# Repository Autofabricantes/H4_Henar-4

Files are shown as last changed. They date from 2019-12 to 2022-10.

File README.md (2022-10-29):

# Henar-4

Hi! Welcome to the **Henar#4 Repository**, please read carefully this welcome page that describes the full content.

This repository is may miss some important points (after many months, I know :'( ) Please if whatever doubt you have is not yet solved contact us somehow (email, Github, etc)

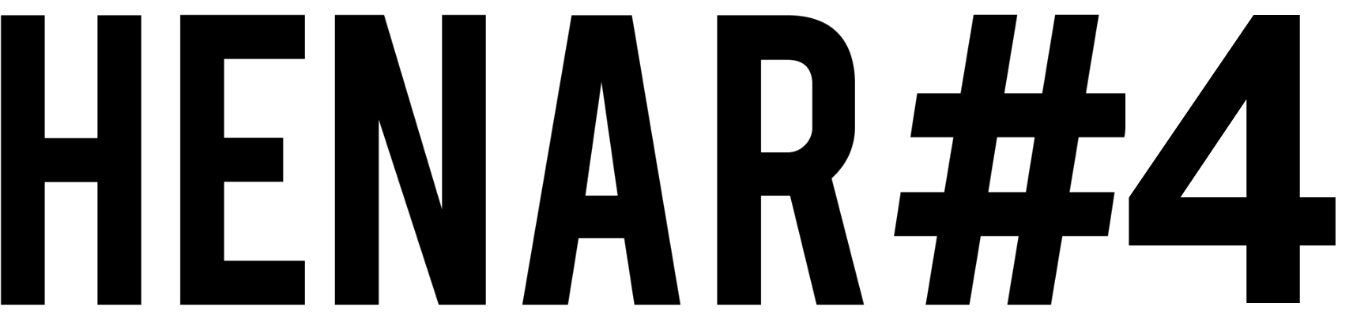
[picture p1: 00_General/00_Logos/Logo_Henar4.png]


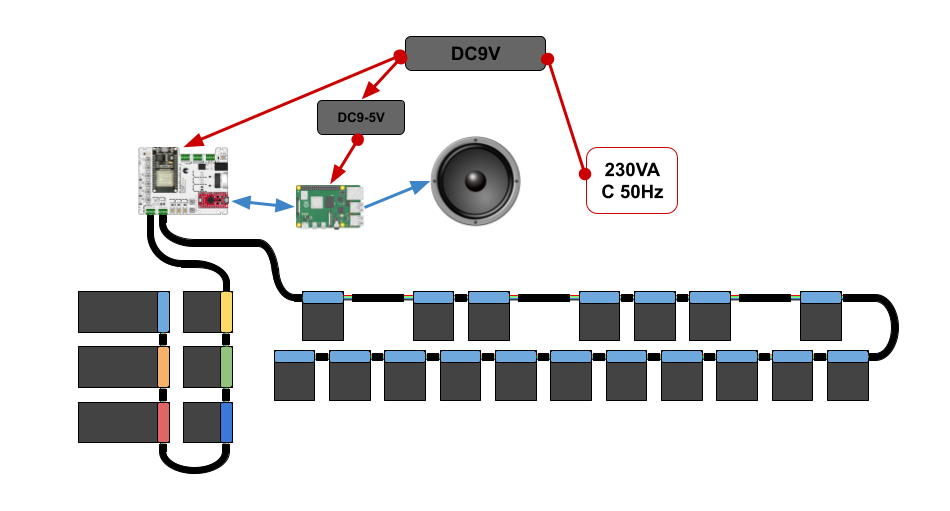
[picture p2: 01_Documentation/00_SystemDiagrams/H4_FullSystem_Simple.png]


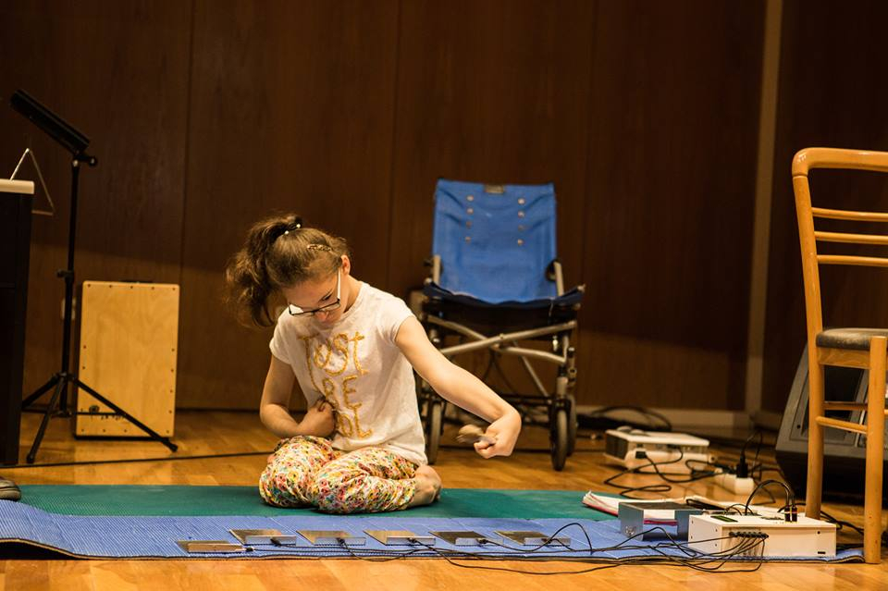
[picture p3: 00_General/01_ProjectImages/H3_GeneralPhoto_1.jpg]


## Project Scope
The **Henar#4** is a Open Source MIDI percussion instrument designed to perform live. Its main characteristics are:

**Open Source:** The Henar#4 has been designed and build with Open Source HW and SW and using accesible manufacturing technologies in order for it to be very affordable and easily moded.
**Build Flexibility:** The Henar#4 has been designed to allow a large number of different configurations (HMI elements in order to cope with the specific neccessities of each user.
**Stand Alone:** The Henar#4 is an instrument designed to be played live, therefore it is a Plug&Play device which does not need of extra elements to be played.
**Pheriperic Flexibility:** Besides being a Plug&Play device, the Henar#4 allows its connection with other sound devices such as speakers and alternative MIDI devices.
 
## History and Collaborators
The Henar#4 is part of a longer project started by the _Celeo Proyectos_ and _Un Instrumento para Henar_ in 2015. Its initial objective is to build a proper adapted instrument for Henar, a woman from Cuenca (Spain) that plays in an orchestra.

Apart from the instrument (which has three previous versions which will be described later) the project aims to build up a platform for the community of developers, users and enthusiasts to work toguether towards new ways to socialize with music and make it accesible for everyone. This is achieved not only though the development of the instrument itself but also through the creation of didactic materials and the organization of events such as DiverS+S 2017 (http://www.diversos.eu/), where various projects were presented and put in common, in order to create links and an active net.

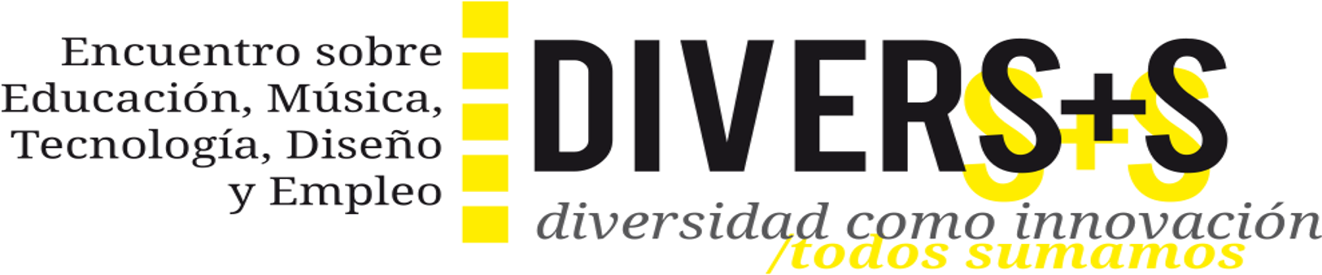
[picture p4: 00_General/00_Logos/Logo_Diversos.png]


The collaborators of this project are:
## Celeo Proyectos

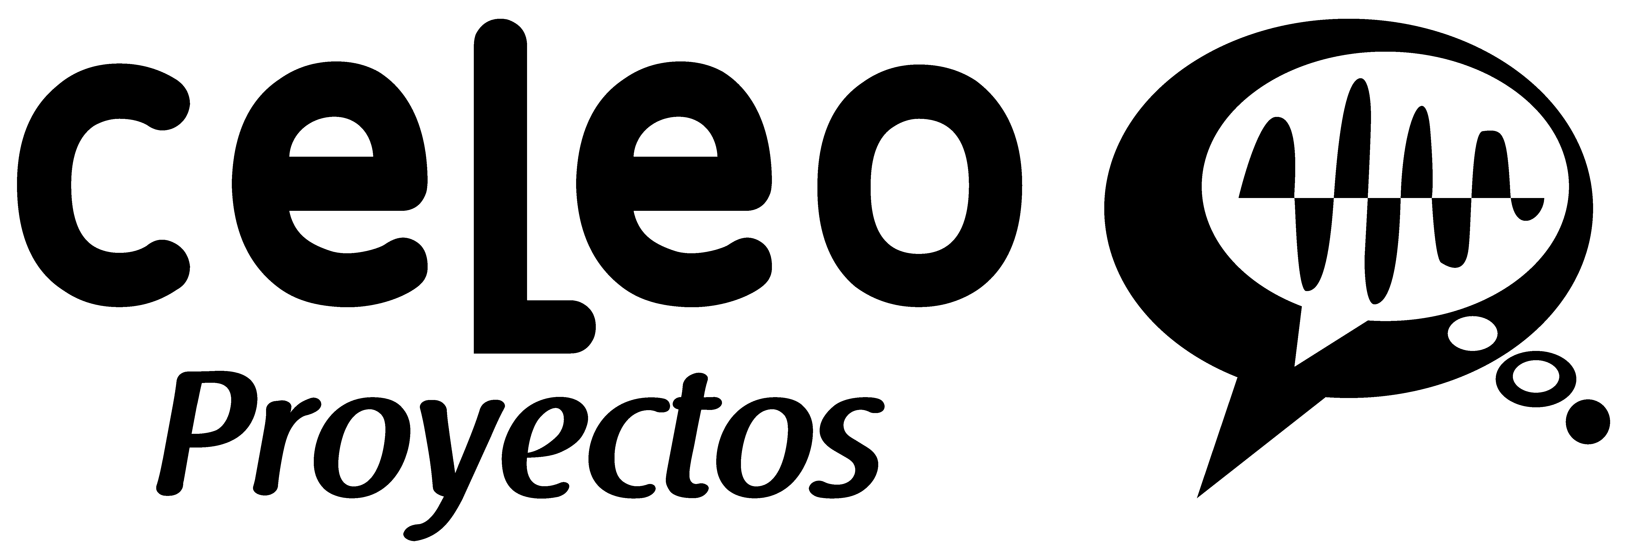
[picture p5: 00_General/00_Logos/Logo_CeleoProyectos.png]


## Un instrumento para Henar



### Website: www.centroceleo.es/henar
### Contact: uninstrumentoparahenar@gmail.com

## Autofabricantes
**_Autofabricantes_** in an association based in _Medialab-Prado_, Madrid. It develops several _Open Source_ technological solutions in the medical and accesibility field. It's main development lines right now are:
* Myoelectric Hand Prothesis for children.
* 3D printed hand prosthesis for children (both experimental like __SuperGizz__ and standard).
* **_Henar#3_** instrument (The one this Wiki covers).

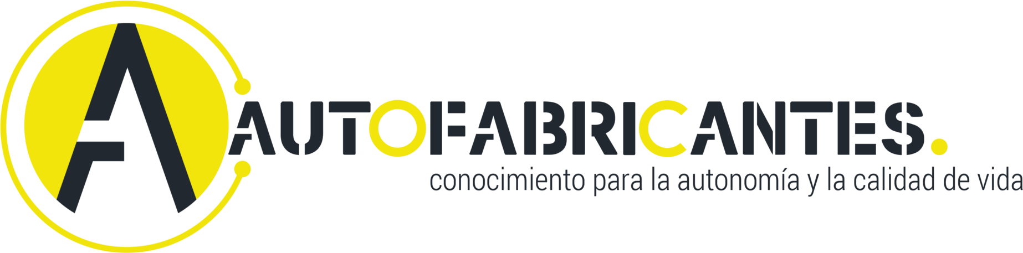
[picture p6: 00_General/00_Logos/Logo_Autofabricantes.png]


### Website: www.autofabricantes.org
### Contact: info@autofabricantes.org

## Los Hacedores
_**Los Hacedores**_ is a 3D Prototyping, design and printing company based in Madrid. They make use of the latest technologies regarding Laser cutting and 3D Printing with a variety of materials and techniques.

They have collaborated both in the fabrication and desing of the mechanical parts of the Henar#4.



### Website: https://loshacedores.com/
### Contact: https://loshacedores.com/contacto/

# About the previous Henar (Henar#1, Henar#2, Henar#3)
The Un instrumento para Henar project has already developed two previous versions of the instruments.

## Henar#3: https://github.com/Autofabricantes/H3_Henar-3

## Scope of the Wiki
This Wiki aims to concentrate all the knowledge of the project. This covers:

 -Global description of the project and its subsystems.
 -Description of all the files in the repository.
 -Description of all the elements and their evolution.
 -Assembly Guide of all the elements (HW, SW, Mechanical).
 -Common problems faced when building and configuration.

# Improvements to be done:
The improvements that a new developper could implement would be:

- Use the ESP32 as an I2C Slave to create a BLE MIDI
- Improve code to allow for the use of the RGB LEDs in the H4_MainBoard (Was not done because of memory limits in Arduino Leonardo)
- Correct the EEPROM corruption in H4_PadController

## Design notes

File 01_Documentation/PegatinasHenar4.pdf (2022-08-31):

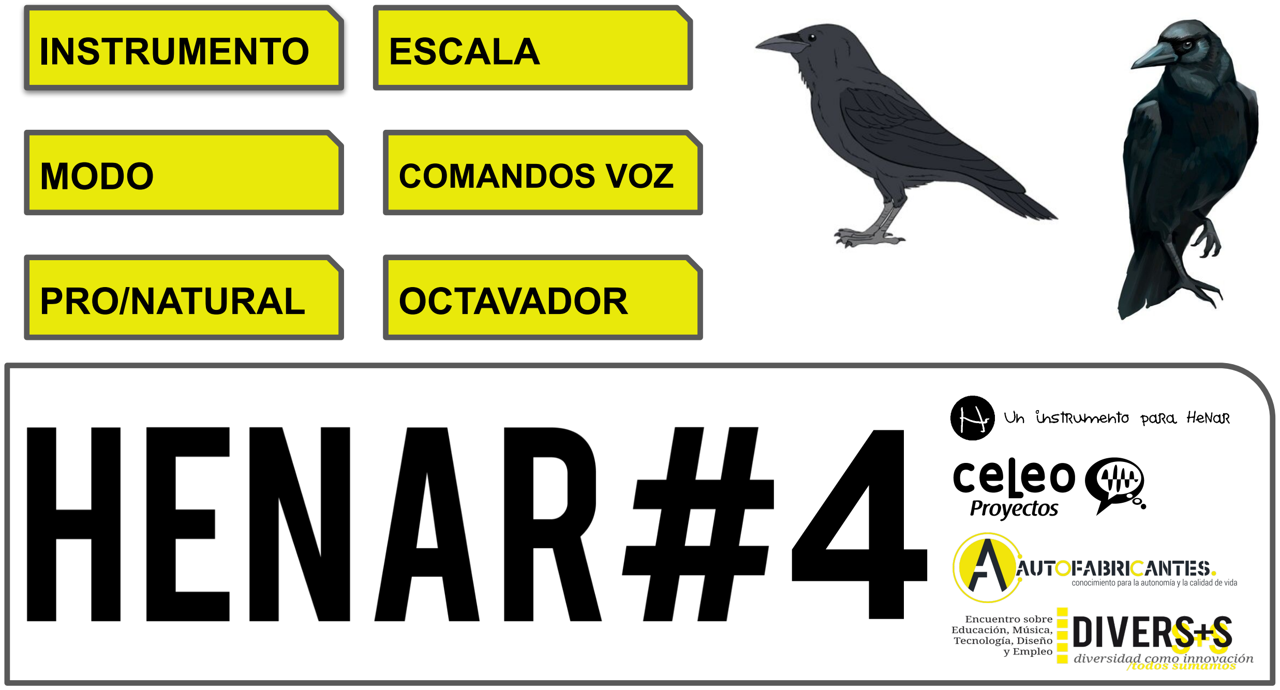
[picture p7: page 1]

INSTRUMENTO | ESCALA
MODO | COMANDOS VOZ
PRO/NATURAL | OCTAVADOR
4

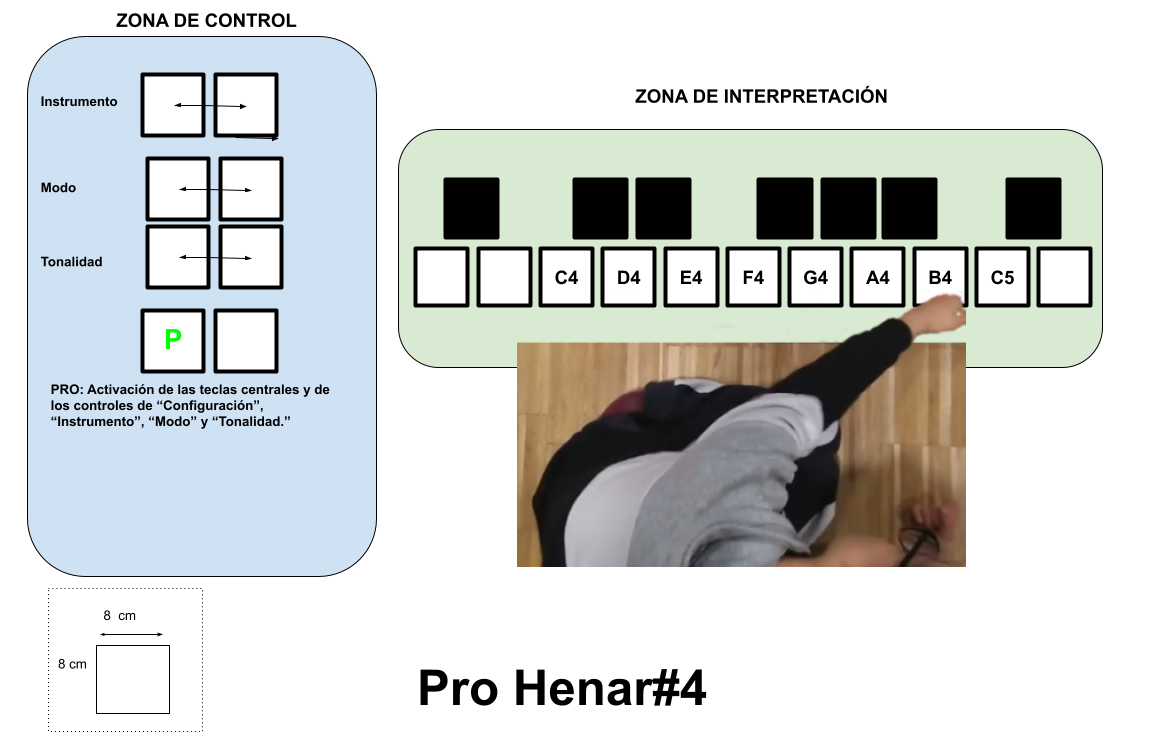
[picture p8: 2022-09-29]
01_Documentation/00_SystemDiagrams/H4_PanelDesign_01.png

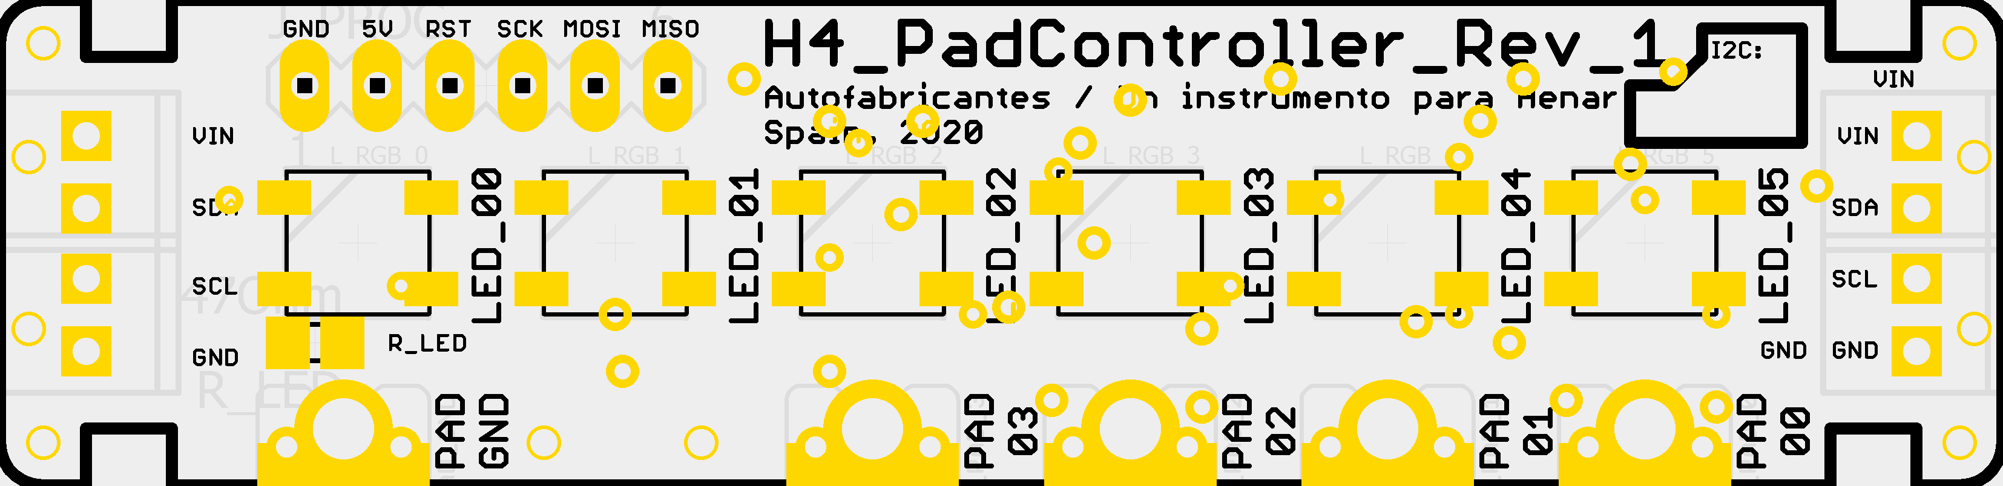
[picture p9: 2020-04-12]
02_Elements/H4_PadController_Rev_2/02_HW/eagleUp/eagleUp_H4_PadController_Rev_1_board_top.png

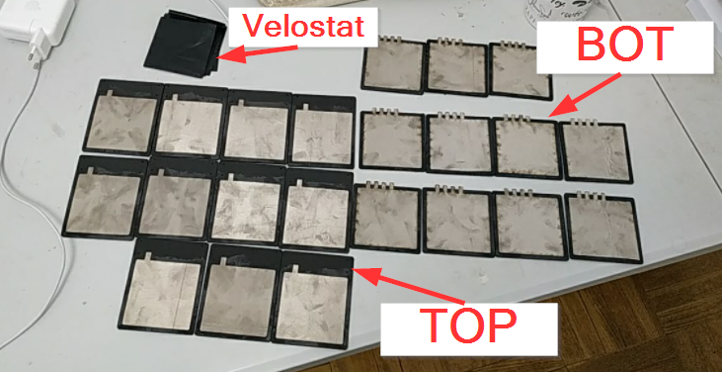
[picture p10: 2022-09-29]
02_Elements/H4_PadController_Rev_2/00_Documentation/H4_Velostat_02.png

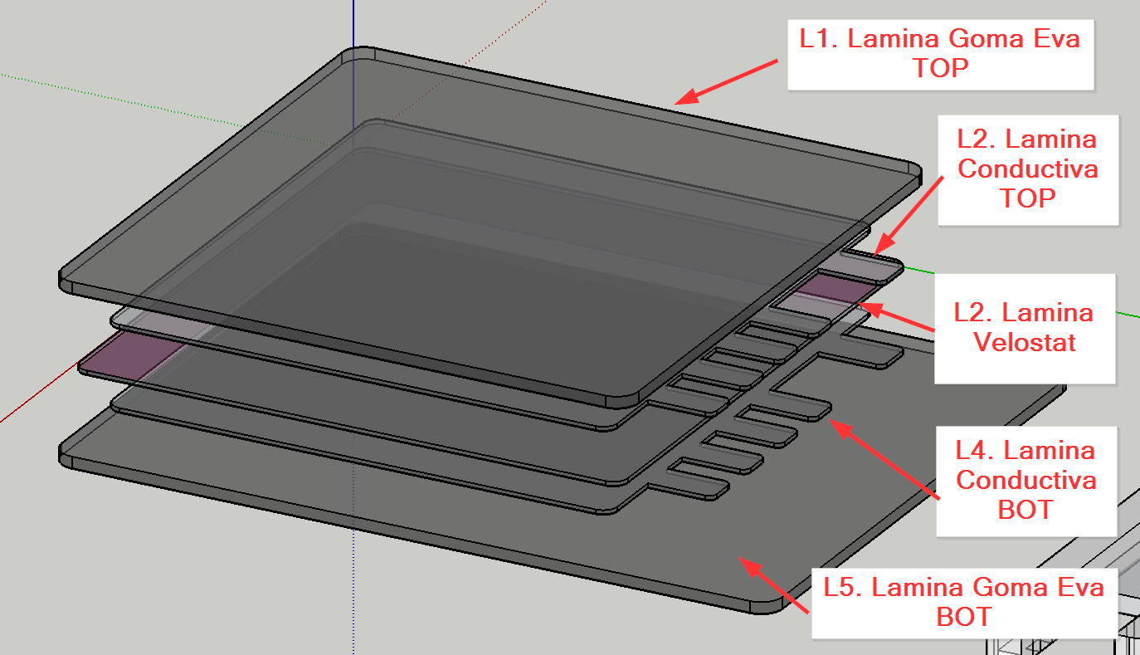
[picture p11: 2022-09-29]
02_Elements/H4_PadController_Rev_2/00_Documentation/H4_Pad_03.png

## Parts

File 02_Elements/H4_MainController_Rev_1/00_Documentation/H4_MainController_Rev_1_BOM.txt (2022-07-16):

Partlist

Exported from H4_MainController_Rev_1.brd at 10/05/2022 11:15

EAGLE Version 7.6.0 Copyright (c) 1988-2016 CadSoft

Assembly variant: 

Part         Value               Package             Library                           Position (mm)         Orientation

C_LED        100uF               C1210               adafruit                          (11 68)               R0
C_LED_00     100nF               C0805K              adafruit                          (6.5 61.5)            R90
C_LED_01     100nF               C0805K              adafruit                          (6.5 52.5)            R90
C_LED_02     100nF               C0805K              adafruit                          (6.5 43.5)            R90
C_LED_03     100nF               C0805K              adafruit                          (6.5 34.5)            R90
C_LED_04     100nF               C0805K              adafruit                          (6.5 25.5)            R90
C_LED_05     100nF               C0805K              adafruit                          (6.5 16.5)            R90
C_LED_ARD_00 100nF               C0805K              adafruit                          (64 15)               R90
C_LED_ARD_01 100nF               C0805K              adafruit                          (64 5)                R90
C_VR_0       330nF               C0805               adafruit                          (81.5 51.5)           R90
C_VR_1       100nF               C0805               adafruit                          (81.5 56.5)           R270
J_CON_00                         1X02_2.54_SCREWTERM SparkFun-Connectors               (9.75 3)              R0
J_CON_01                         1X02_2.54_SCREWTERM SparkFun-Connectors               (28.75 3)             R0
J_CON_02                         1X02_2.54_SCREWTERM SparkFun-Connectors               (23.75 3)             R0
J_CON_03                         1X02_2.54_SCREWTERM SparkFun-Connectors               (14.75 3)             R0
J_MIDI       MIDI_CONN_FEMALE    DIN_5_FEMALE        SparkFun-Connectors               (91 37)               R90
J_PW                             DCJ0303             con-jack                          (89 54)               R90
J_PWSW                           1X02_2.54_SCREWTERM SparkFun-Connectors               (84.25 64)            R180
J_PWSW_0                         1X02_2.54_SCREWTERM SparkFun-Connectors               (79.25 64)            R180
J_SW_00                          1X02_2.54_SCREWTERM SparkFun-Connectors               (70 64)               R180
J_SW_01                          1X02_2.54_SCREWTERM SparkFun-Connectors               (65 64)               R180
J_SW_02                          1X02_2.54_SCREWTERM SparkFun-Connectors               (56.25 64)            R180
J_SW_03                          1X02_2.54_SCREWTERM SparkFun-Connectors               (51.25 64)            R180
L_RGB_0                          WS2812B             SparkFun-LED                      (11 61.5)             R90
L_RGB_1                          WS2812B             SparkFun-LED                      (11 52.5)             R90
L_RGB_2                          WS2812B             SparkFun-LED                      (11 43.5)             R90
L_RGB_3                          WS2812B             SparkFun-LED                      (11 34.5)             R90
L_RGB_4                          WS2812B             SparkFun-LED                      (11 25.5)             R90
L_RGB_5                          WS2812B             SparkFun-LED                      (11 16.5)             R90
L_RGB_ARD_00                     WS2812B             SparkFun-LED                      (60 15)               R90
L_RGB_ARD_01                     WS2812B             SparkFun-LED                      (60 5)                R90
R_ARD_RX     0Ohm                M0805               adafruit                          (71 31)               R0
R_ARD_TX     0Ohm                M0805               adafruit                          (71 28)               R0
R_ESP_I2C_0  0Ohm                M0805               adafruit                          (21 12)               R270
R_ESP_I2C_1  0Ohm                M0805               adafruit                          (18 12)               R270
R_ESP_RX     0Ohm                M0805               adafruit                          (71 47)               R0
R_ESP_RX_2   0Ohm                M0805               adafruit                          (71 39)               R0
R_ESP_TX     0Ohm                M0805               adafruit                          (71 44)               R0
R_ESP_TX_2   0Ohm                M0805               adafruit                          (71 36)               R0
R_I2C_0      10kOhm              M0805               adafruit                          (28.5 12)             R90
R_I2C_1      10kOhm              M0805               adafruit                          (25.5 12)             R270
R_LED        47Ohm               M0805               adafruit                          (7 68)                R90
R_MIDI_0     220Ohm              M0805               adafruit                          (80 42.5)             R0
R_MIDI_1     220Ohm              M0805               adafruit                          (80 32.5)             R0
R_PAD_00     220Ohm              M0805               adafruit                          (2.5 12)              R180
R_PAD_01     220Ohm              M0805               adafruit                          (2.5 21)              R180
R_PAD_02     220Ohm              M0805               adafruit                          (2.5 30)              R180
R_PAD_03     220Ohm              M0805               adafruit                          (2.5 39)              R180
R_SW_0       10kOhm              M0805               adafruit                          (52 11)               R180
R_SW_1       10kOhm              M0805               adafruit                          (45 11)               R180
R_SW_02      10kOhm              M0805               adafruit                          (38 11)               R180
R_SW_RST     10kOhm              M0805               adafruit                          (89.5 63.5)           R270
SW_00        PTS525SM08          SM08                pts525_20                         (52 5)                R270
SW_01        PTS525SM08          SM08                pts525_20                         (45 5)                R270
SW_02        PTS525SM08          SM08                pts525_20                         (38 5)                R270
SW_RST       PTS525SM08          SM08                pts525_20                         (95 64)               R0
U_0          ARDUINO_MINI        ARDUINO_MINI        SparkFun-Boards                   (83.5 16)             R270
U_1          ESP32_DEVKIT        ESP32_DEVKIT        DOIT_ESP32_DEVKIT                 (30 75)               R180
U_PAD_0      PAD_CONNECTOR_MULTI PAD_CONNECTOR_MULTI atfHenar_customLib                (2 16.5)              R180
U_PAD_1      PAD_CONNECTOR_MULTI PAD_CONNECTOR_MULTI atfHenar_customLib                (2 25.5)              R180
U_PAD_2      PAD_CONNECTOR_MULTI PAD_CONNECTOR_MULTI atfHenar_customLib                (2 34.5)              R180
U_PAD_3      PAD_CONNECTOR_MULTI PAD_CONNECTOR_MULTI atfHenar_customLib                (2 43.5)              R180
U_PAD_GND    PAD_CONNECTOR_MULTI PAD_CONNECTOR_MULTI atfHenar_customLib                (2 62)                R180
U_VR_0       MC78GENERICDT       DPAK-3              _hhn_78xx_79xx_NCV78xx_d2pak_dpak (69.5 53.5)           R90

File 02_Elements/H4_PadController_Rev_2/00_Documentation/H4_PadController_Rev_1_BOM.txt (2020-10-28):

Partlist exported from C:/Users/34663/Documents/GitHub/Henar-4/02_Elements/H4_PadController_Rev_1/02_HW/H4_PadController_Rev_1.sch at 16/06/2020 11:56

Qty Value               Device              Package             Parts                                                Description                                                                         AVAILABILITY DESCRIPTION                                        MF      MP                  MPN OC_FARNELL OC_NEWARK PACKAGE       PRICE PROD_ID   VALUE          
1                       DIODESOD-123        SOD-123             D_RST                                                Diode                                                                                                                                                                                                                                                 
4                       M022.54MM_SCREWTERM 1X02_2.54_SCREWTERM J_CON_00, J_CON_01, J_CON_02, J_CON_03               Standard 2-pin 0.1" header. Use with                                                                                                                                                                                                                  
1                       MA06-1              MA06-1              J_PROG                                               PIN HEADER                                                                                                                                                                          unknown    unknown                                                
6                       WS2812B             WS2812B             L_RGB_0, L_RGB_1, L_RGB_2, L_RGB_3, L_RGB_4, L_RGB_5 WS2812B - Intelligent control LED integrated light source                                                                                                                                                                    DIO-12503                
3   0.1uF               C-USC0805           C0805               C_ATM_0, C_ATM_1, C_ATM_2                            CAPACITOR, American symbol                                                                                                                                                                                                                            
1   100nF               C-USC0805           C0805               C_VR_1                                               CAPACITOR, American symbol                                                                                                                                                                                                                            
1   100uF               C-USC1210           C1210               C_LED                                                CAPACITOR, American symbol                                                                                                                                                                                                                            
3   10kOhm              R-US_M0805          M0805               R_I2C_0, R_I2C_1, R_RST                              RESISTOR, American symbol                                                                                                                                                                                                                             
4   220Ohm              R-US_M0805          M0805               R_PAD_00, R_PAD_01, R_PAD_02, R_PAD_03               RESISTOR, American symbol                                                                                                                                                                                                                             
1   330nF               C-USC0805           C0805               C_VR_0                                               CAPACITOR, American symbol                                                                                                                                                                                                                            
1   47Ohm               R-US_M0805          M0805               R_LED                                                RESISTOR, American symbol                                                                                                                                                                                                                             
1   ABM8-24.000MHZ-B2-T ABM8-24.000MHZ-B2-T OSCSC320X250X100N   U_OSC                                                Crystal 20MHz ±20ppm (Tol) ±30ppm (Stability) 18pF FUND 80Ohm 4-Pin Mini-CSMD T/R Unavailable   24MHz �20ppm Crystal 18pF 50 Ohms 4-SMD, No Lead  Abracon ABM8-24.000MHZ-B2-T                          SMD-4 Abracon None                           
1   ATMEGA328P_TQFP     ATMEGA328P_TQFP     TQFP32-08           U_ATMEGA328                                                                                                                                                                                                                                                                       IC-09069  ATMEGA328P_TQFP
1   MC78GENERICDT       MC78GENERICDT       DPAK-3              U_VR_0                                               78xx SMD (D2PAK, DPAK)                                                                                                                                                                                                                                
5   PAD_CONNECTOR_MULTI PAD_CONNECTOR_MULTI PAD_CONNECTOR_MULTI U_PAD_0, U_PAD_1, U_PAD_2, U_PAD_3, U_PAD_GND

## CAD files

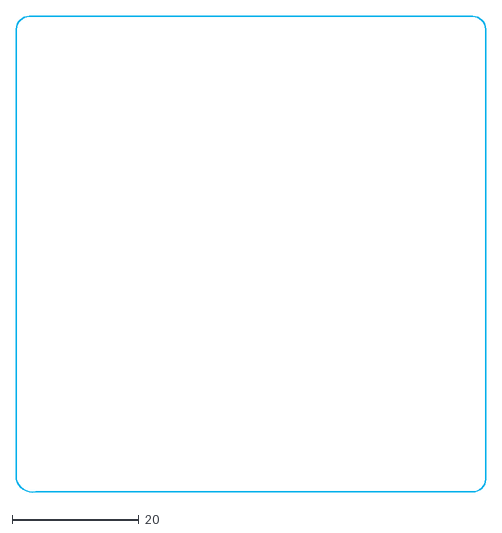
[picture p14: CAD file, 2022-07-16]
02_Elements/H4_PadController_Rev_2/01_Resources/H4_Pad_80x80mm_Velostat.dxf
74.0 x 75.1

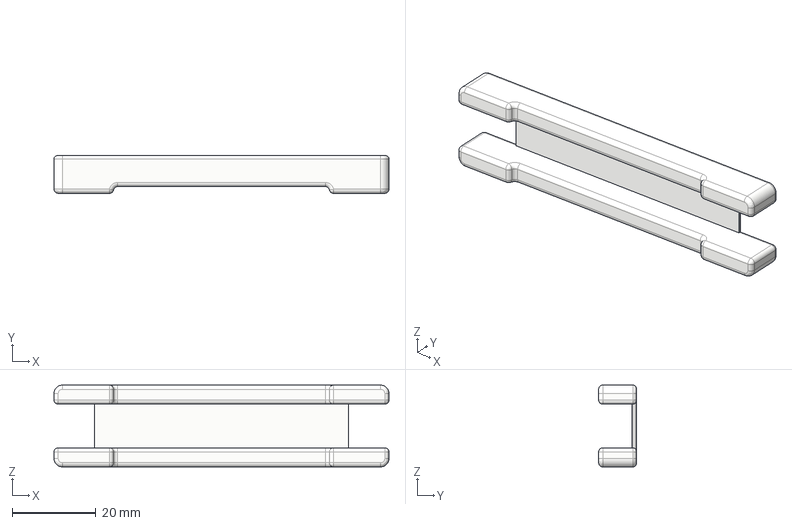
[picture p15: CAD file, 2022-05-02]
02_Elements/H4_Cover_Rev_1/Cubreplaca_henar-autofabricantes_V2.step
80.0 x 9.00 x 19.5 mm

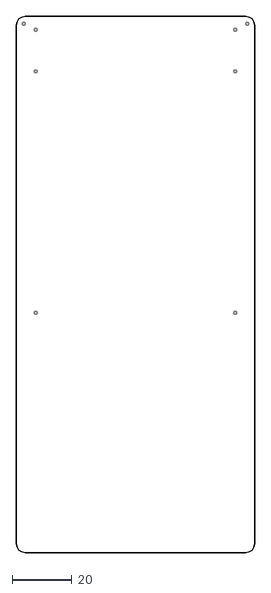
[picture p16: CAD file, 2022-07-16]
02_Elements/H4_PadController_Rev_2/01_Resources/H4_Pad_160x80mm_FoamBot.dxf
80.0 x 180.0

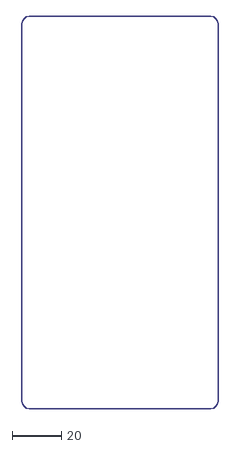
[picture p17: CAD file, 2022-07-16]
02_Elements/H4_PadController_Rev_2/01_Resources/H4_Pad_160x80mm_FoamTop.dxf
80.0 x 160.0

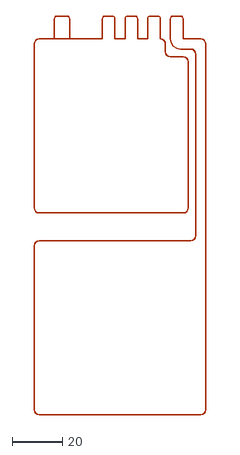
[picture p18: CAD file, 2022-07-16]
02_Elements/H4_PadController_Rev_2/01_Resources/H4_Pad_160x80mm_ConductiveTop.dxf
68.0 x 158.0

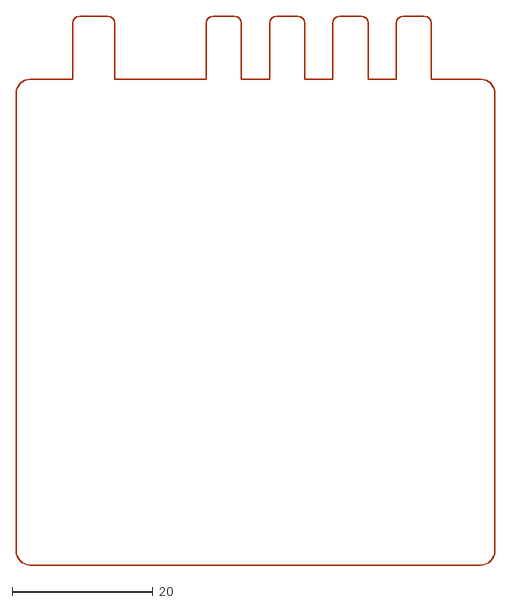
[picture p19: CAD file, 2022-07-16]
02_Elements/H4_PadController_Rev_2/01_Resources/H4_Pad_80x80mm_Conductive.dxf
68.0 x 78.0

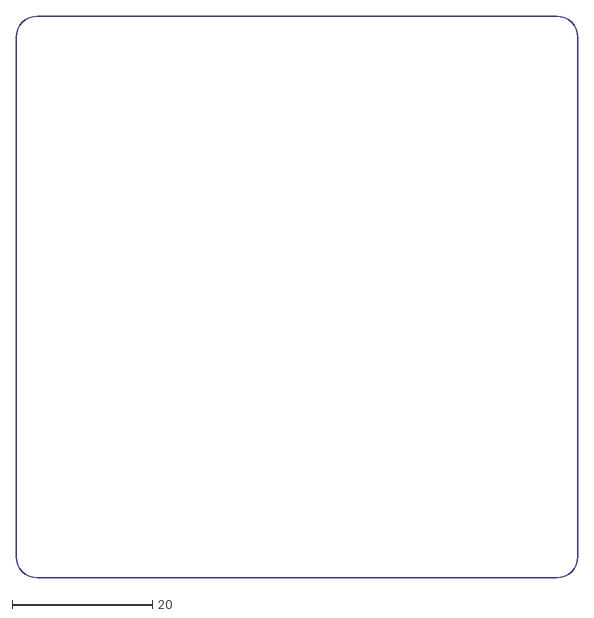
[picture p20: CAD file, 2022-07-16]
02_Elements/H4_PadController_Rev_2/01_Resources/H4_Pad_80x80mm_FoamTop.dxf
80.0 x 80.0

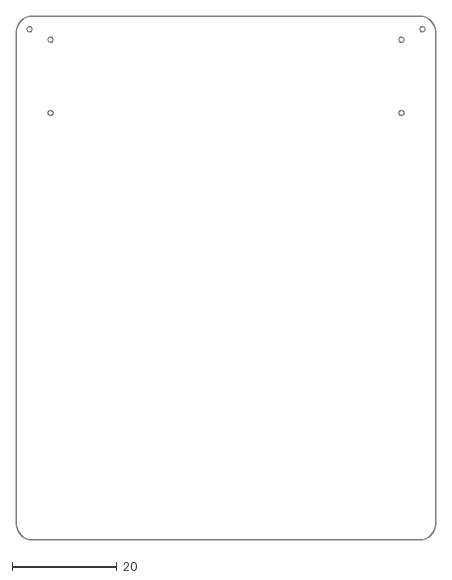
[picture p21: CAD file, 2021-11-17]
02_Elements/H4_PadController_Rev_2/01_Resources/H4_Pad_80x80mm_FoamBot.dxf
80.0 x 100.0

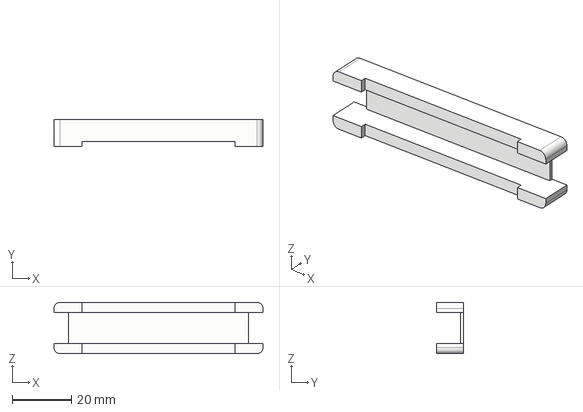
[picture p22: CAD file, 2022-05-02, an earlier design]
02_Elements/H4_Cover_Rev_1/Cubreplaca_henar-autofabricantes_V1.step
70.4 x 9.00 x 17.3 mm

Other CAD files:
02_Elements/H4_Cover_Rev_1/cubre_placa_henar_V2.stl
02_Elements/H4_Cover_Rev_1/cubre_placa_henar_V1.stl
02_Elements/H4_MainController_Rev_1/00_Documentation/H4_MainController_Rev_1_3DModel/H4_MainController_Rev_1_3DModel.skp
02_Elements/H4_MainController_Rev_1/00_Documentation/H4_MainController_Rev_1_3DModel/Pro+Micro.skp
02_Elements/H4_MainController_Rev_1/00_Documentation/H4_MainController_Rev_1_3DModel/esp32-hb.skp

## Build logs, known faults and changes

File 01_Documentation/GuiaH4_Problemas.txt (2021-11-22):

Se modifica en el documento:

C:\Program Files (x86)\Arduino\hardware\arduino\avr

La línea:

#uno.build.mcu=atmega328p

por:

uno.build.mcu=atmega328

No funciona.

Se modifica el documento:

C:\Users\34663\AppData\Local\Arduino15\packages\arduino\tools\avrdude\6.3.0-arduino17\etc

La línea 8618:
signature		= 0x1e 0x95 0x14;

por:
signature		= 0x1e 0x95 0x0f;

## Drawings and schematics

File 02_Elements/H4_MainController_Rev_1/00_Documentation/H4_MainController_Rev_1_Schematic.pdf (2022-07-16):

# 10kOhm GND

# 220Ohm GND GND

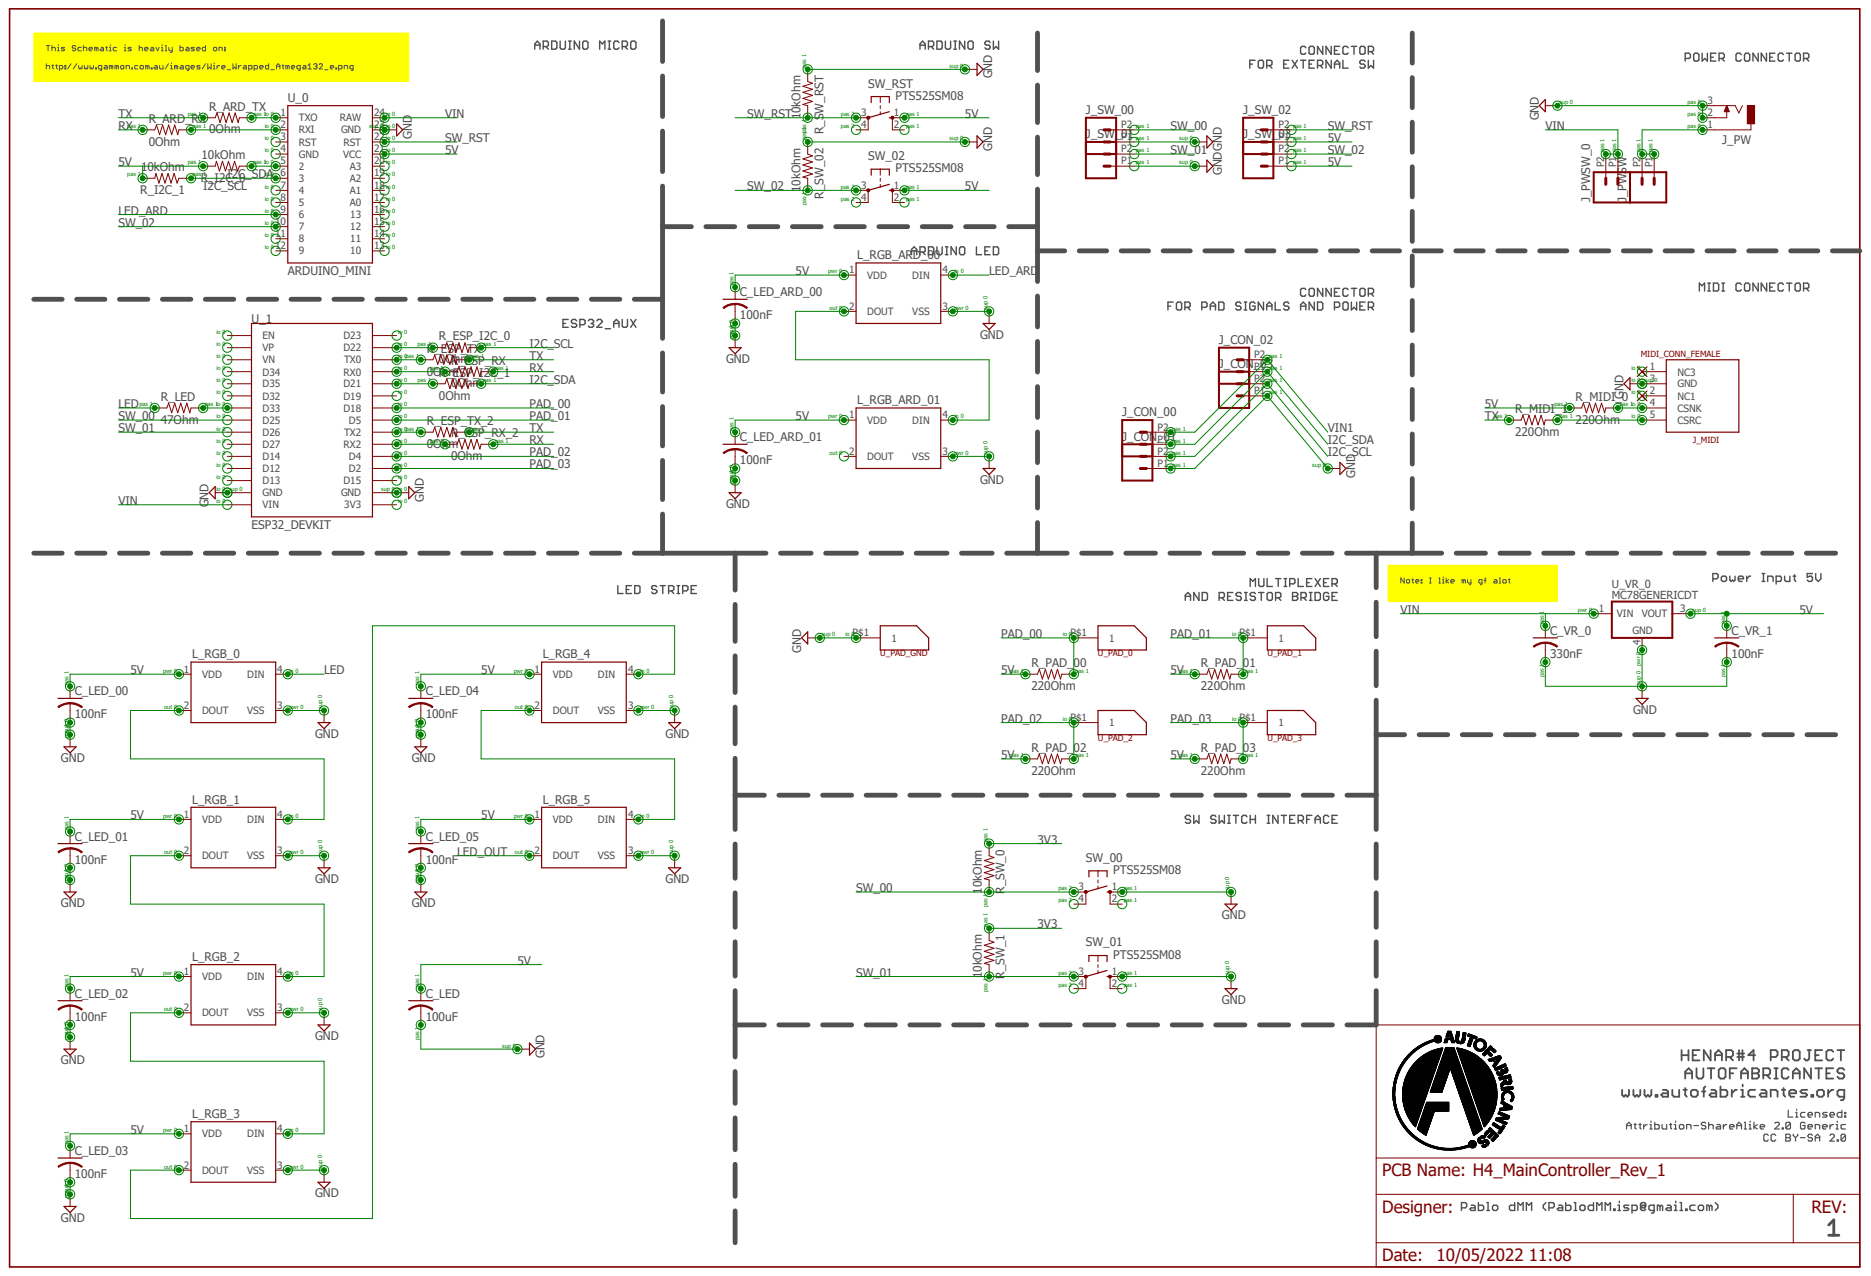
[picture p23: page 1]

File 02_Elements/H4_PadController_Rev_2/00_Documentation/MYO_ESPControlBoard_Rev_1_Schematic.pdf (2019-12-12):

# io 0 sup 0 io 0

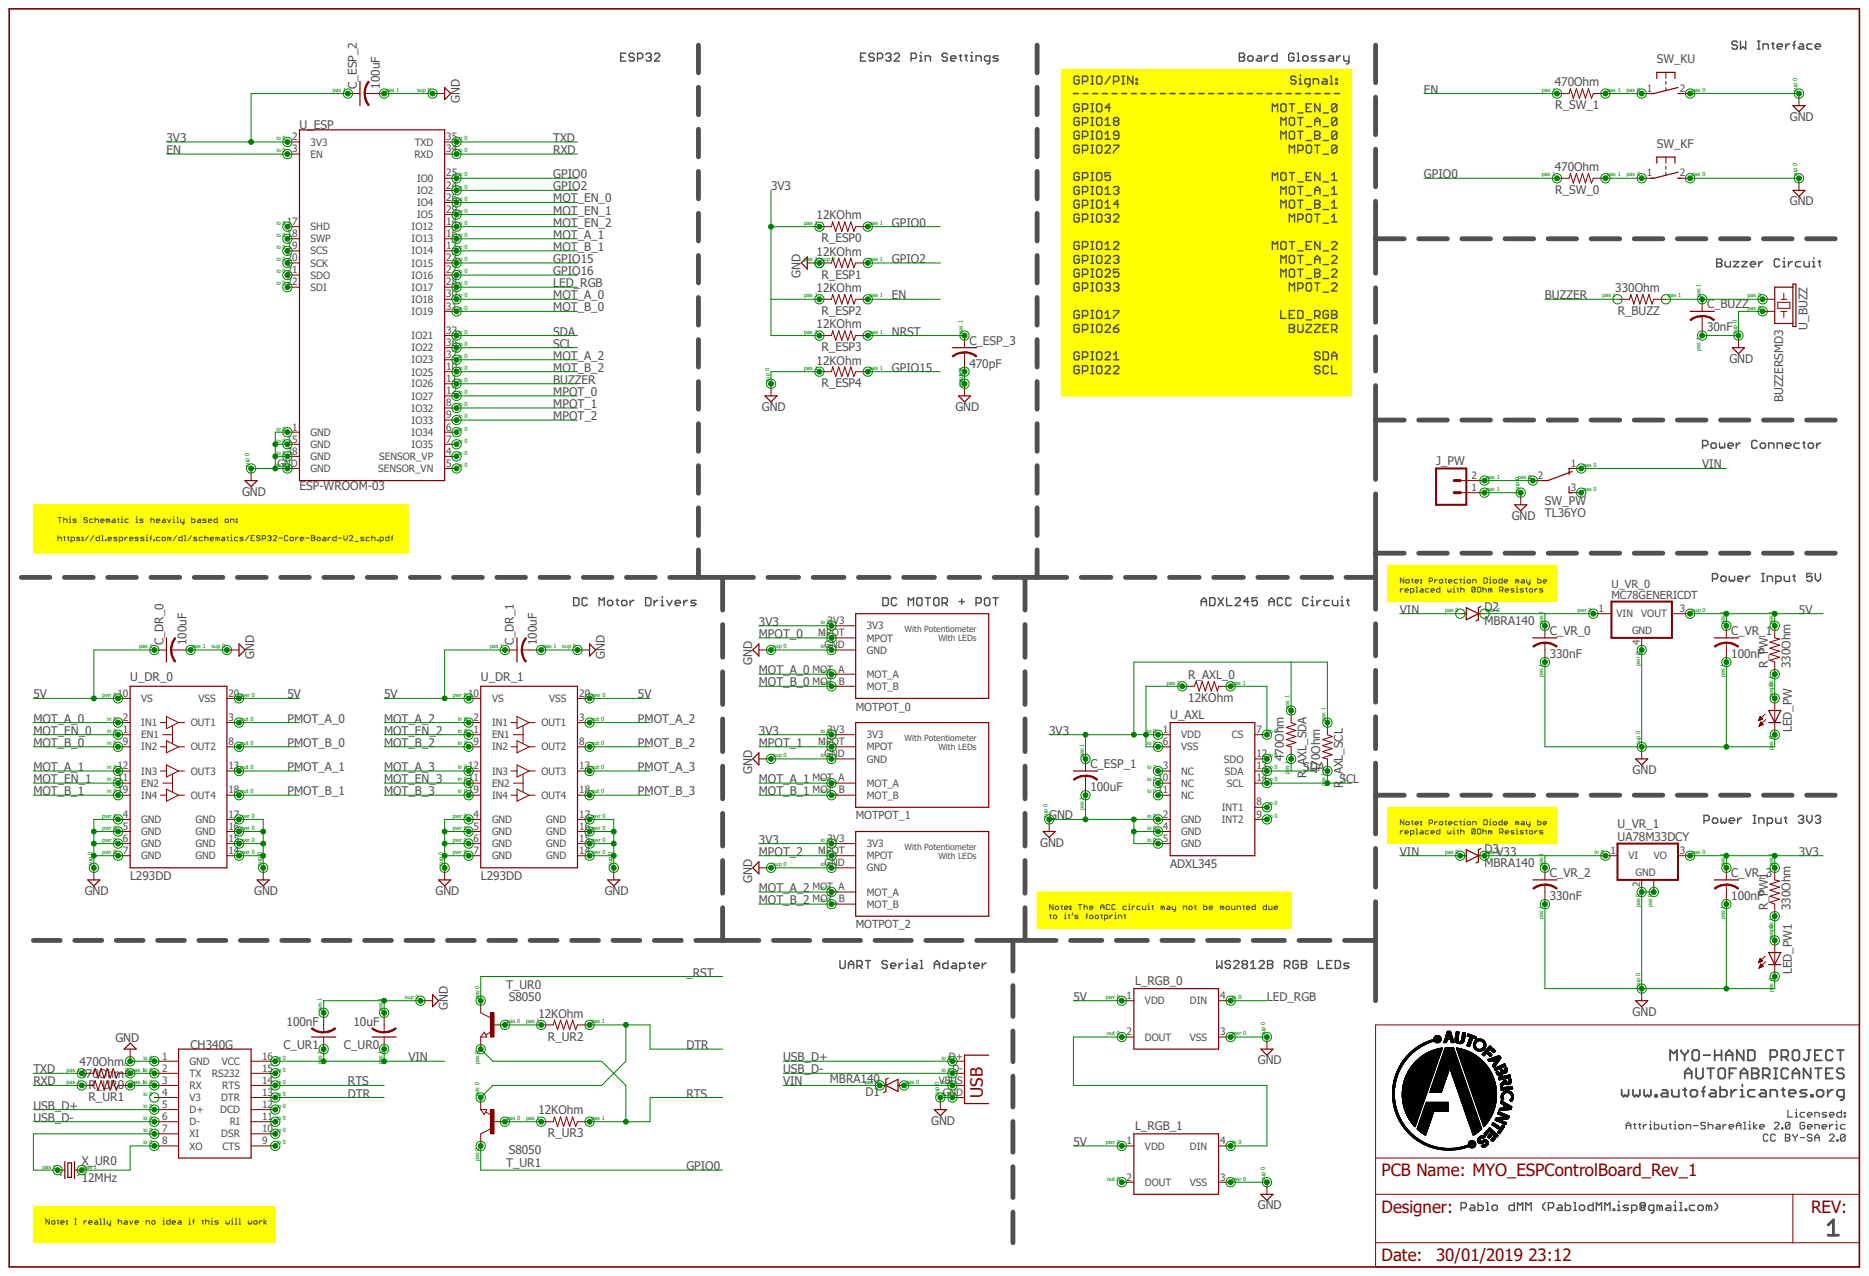
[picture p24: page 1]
330Ohm; GND; ESP-WROOM-03 GND; 470Ohm; 12KOhm; 12MHz; MBRA140; MC78GENERICDT; GND ¹⁰⁰uF; GND GND; UA78M33DCY; 470pF GND; ADXL345; BUZZERSMD³; GND TL36YO; LED_PW R_PW; GND 1; SENSOR_VP; 4 SENSOR_VN; 14 GND 15; 16 SHD 17; SWP 18; SCS 19; GND 38; TXD; 35 RXD; SDI 22; SDO 21; SCK 20; U_ESP; CTS; 9 DSR; 11 DCD; 12 DTR; 13 RTS; 15 VCC; D- VBUS GND R_UR0 R_UR1; VIN 1 4 VOUT; OUT1; GND 4; GND 5; OUT2; VSS; OUT4; GND 6; GND 7; OUT3; 14 GND; 15 GND; 16 GND; MPOT MPOT GND GND; MOT_A MOT_A MOT_B MOT_B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

MOTPOT_0With Potentiometer With LEDs

pas 0 pas 0 pas 0

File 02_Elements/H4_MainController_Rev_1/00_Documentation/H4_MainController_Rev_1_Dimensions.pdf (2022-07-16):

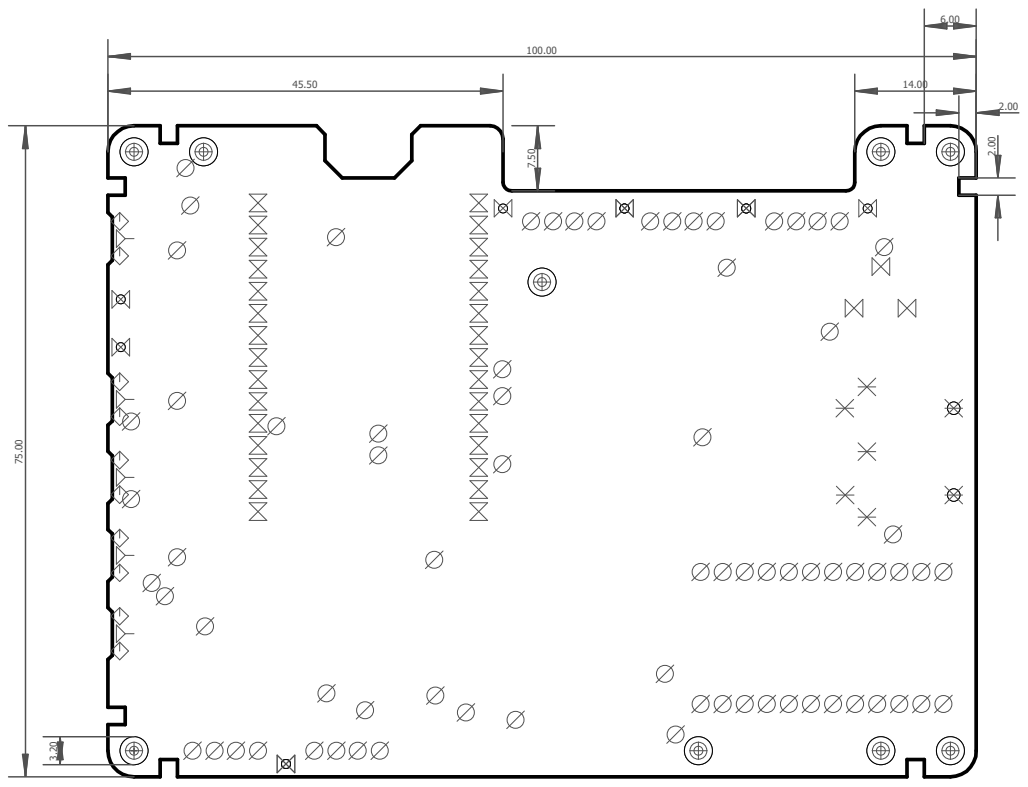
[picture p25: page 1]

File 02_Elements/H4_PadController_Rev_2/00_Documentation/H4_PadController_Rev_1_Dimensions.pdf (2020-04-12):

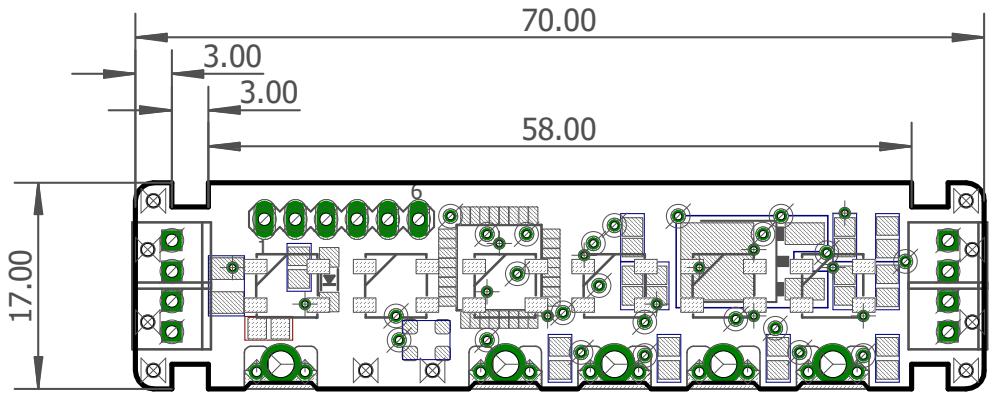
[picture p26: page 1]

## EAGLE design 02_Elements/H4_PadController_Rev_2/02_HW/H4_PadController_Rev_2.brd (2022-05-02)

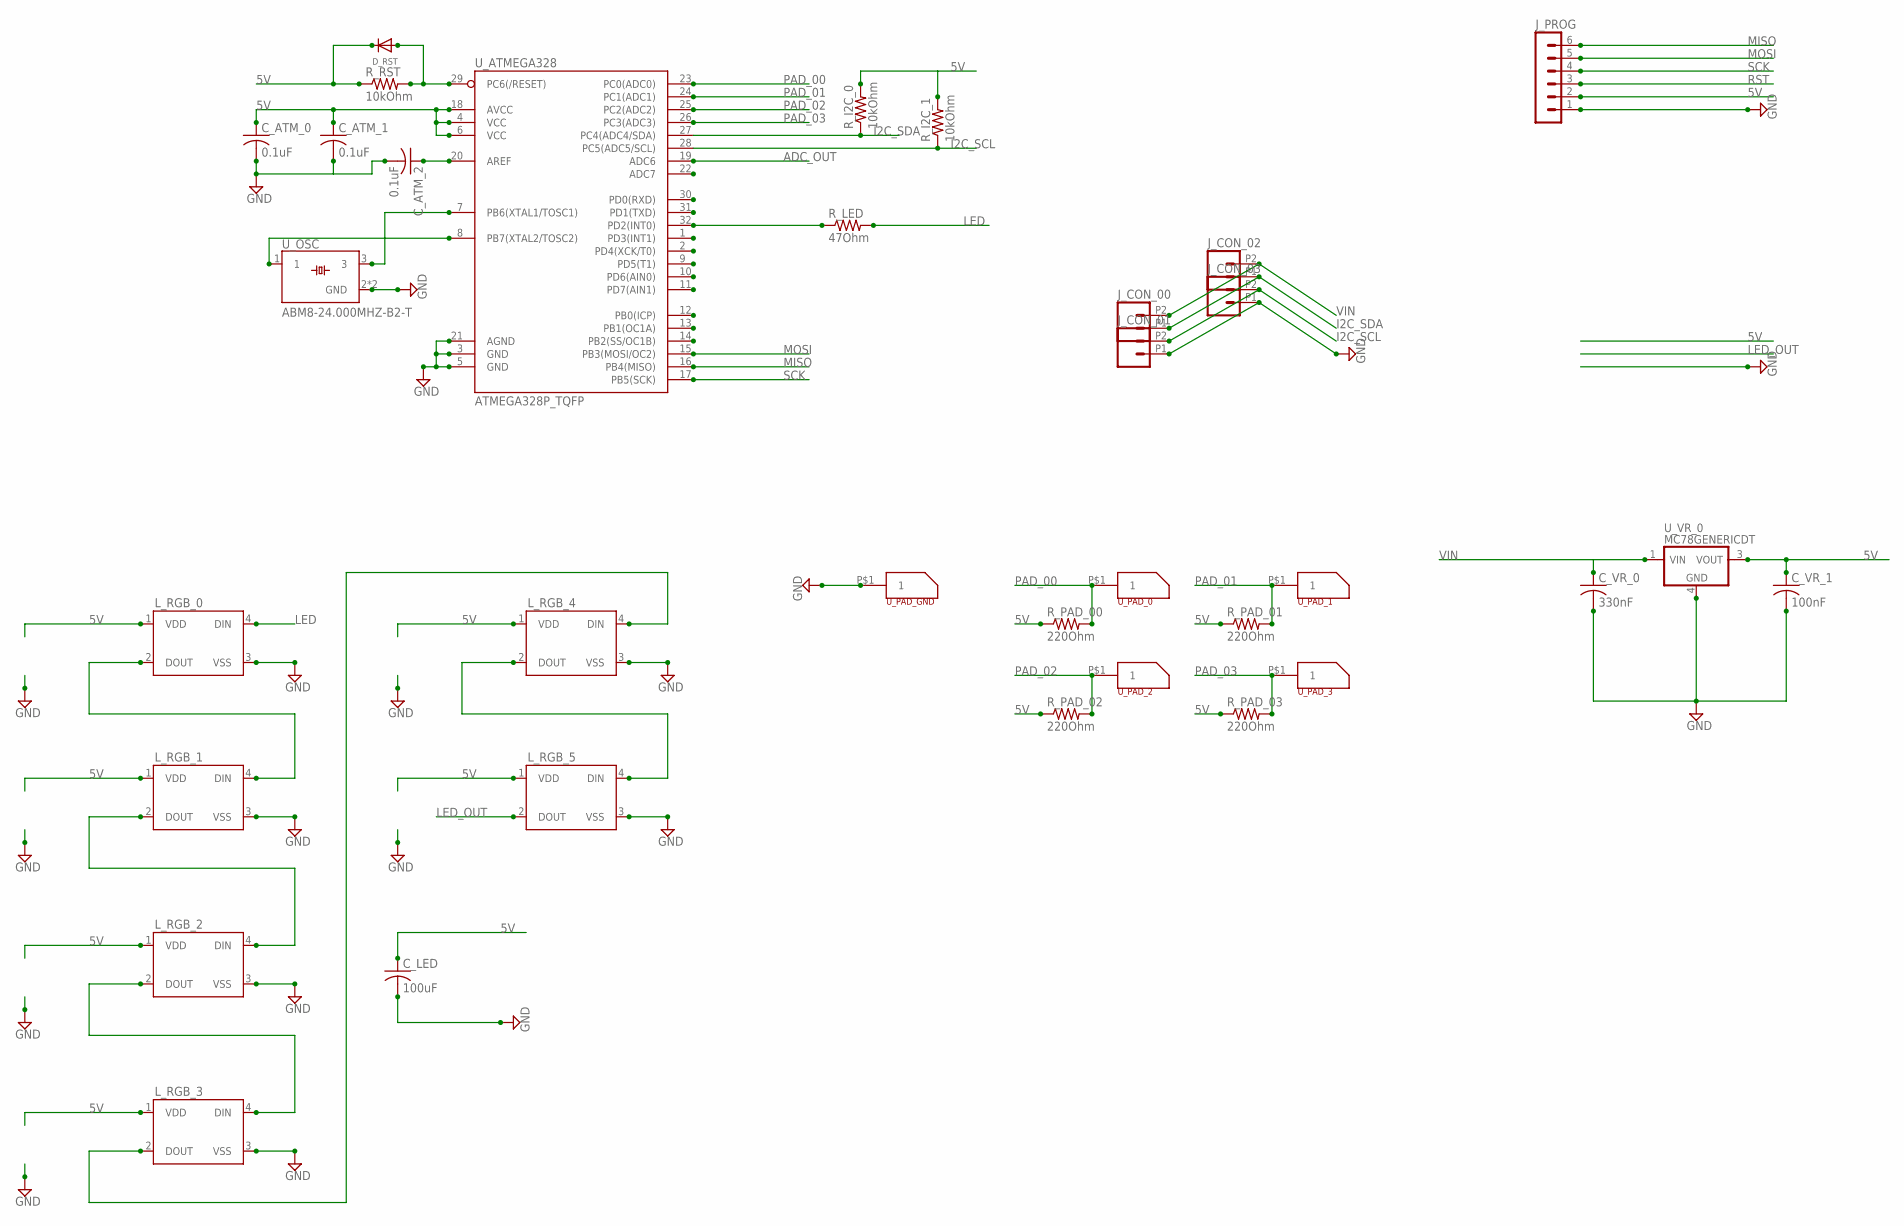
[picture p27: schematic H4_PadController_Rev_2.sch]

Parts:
C_ATM_0, C_ATM_1, C_ATM_2: 0.1uF; C0805
C_LED: 100uF; C1210
C_VR_0: 330nF; C0805
C_VR_1: 100nF; C0805
D_RST: DIODESOD-123; SOD-123
J_CON_00, J_CON_01, J_CON_02, J_CON_03: M022.54MM_SCREWTERM; 1X02_2.54_SCREWTERM
J_PROG: MA06-1
L_RGB_0, L_RGB_1, L_RGB_2, L_RGB_3, L_RGB_4, L_RGB_5: WS2812B
R_I2C_0, R_I2C_1: 10kOhm; M0805
R_LED: 47Ohm; M0805
R_PAD_00, R_PAD_01, R_PAD_02, R_PAD_03: 220Ohm; M0805
R_RST: 10kOhm; M0805
U_ATMEGA328: ATMEGA328P_TQFP; TQFP32-08
U_OSC: ABM8-24.000MHZ-B2-T; OSCSC320X250X100N
U_PAD_0, U_PAD_1, U_PAD_2, U_PAD_3: PAD_CONNECTOR_MULTI
U_PAD_GND: PAD_CONNECTOR_MULTI
U_VR_0: MC78GENERICDT; DPAK-3

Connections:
5V: C_ATM_0.1, C_ATM_1.1, C_LED.1, C_VR_1.1, D_RST.C, J_PROG.2, L_RGB_0.1 (VDD), L_RGB_1.1 (VDD), L_RGB_2.1 (VDD), L_RGB_3.1 (VDD), L_RGB_4.1 (VDD), L_RGB_5.1 (VDD), R_I2C_0.2, R_I2C_1.2, R_PAD_00.1, R_PAD_01.1, R_PAD_02.1, R_PAD_03.1, R_RST.1, U_ATMEGA328.4 (VCC), U_ATMEGA328.6 (VCC), U_ATMEGA328.18 (AVCC), U_VR_0.3 (VOUT)
ADC_OUT: U_ATMEGA328.19 (ADC6)
GND: C_ATM_0.2, C_ATM_1.2, C_ATM_2.2, C_LED.2, C_VR_0.2, C_VR_1.2, J_CON_01.P1 (1), J_CON_03.P1 (1), J_PROG.1, L_RGB_0.3 (VSS), L_RGB_1.3 (VSS), L_RGB_2.3 (VSS), L_RGB_3.3 (VSS), L_RGB_4.3 (VSS), L_RGB_5.3 (VSS), U_ATMEGA328.3 (GND), U_ATMEGA328.5 (GND), U_ATMEGA328.21 (AGND), U_OSC.2 (GND), U_OSC.4 (GND), U_PAD_GND.P$1, U_VR_0.4 (GND)
I2C_SCL: J_CON_01.P2 (2), J_CON_03.P2 (2), R_I2C_1.1, U_ATMEGA328.28 (PC5(ADC5/SCL))
I2C_SDA: J_CON_00.P1 (1), J_CON_02.P1 (1), R_I2C_0.1, U_ATMEGA328.27 (PC4(ADC4/SDA))
LED: L_RGB_0.4 (DIN), R_LED.2
LEDE: L_RGB_3.2 (DOUT), L_RGB_4.4 (DIN)
LED_OUT: L_RGB_5.2 (DOUT)
MISO: J_PROG.6, U_ATMEGA328.16 (PB4(MISO))
MOSI: J_PROG.5, U_ATMEGA328.15 (PB3(MOSI/OC2))
unnamed: U_ATMEGA328.7 (PB6(XTAL1/TOSC1)), U_OSC.3
unnamed: L_RGB_2.2 (DOUT), L_RGB_3.4 (DIN)
unnamed: C_ATM_2.1, U_ATMEGA328.20 (AREF)
unnamed: U_ATMEGA328.8 (PB7(XTAL2/TOSC2)), U_OSC.1
unnamed: R_LED.1, U_ATMEGA328.32 (PD2(INT0))
unnamed: L_RGB_1.2 (DOUT), L_RGB_2.4 (DIN)
unnamed: L_RGB_0.2 (DOUT), L_RGB_1.4 (DIN)
unnamed: L_RGB_4.2 (DOUT), L_RGB_5.4 (DIN)
PAD_00: R_PAD_00.2, U_ATMEGA328.23 (PC0(ADC0)), U_PAD_0.P$1
PAD_01: R_PAD_01.2, U_ATMEGA328.24 (PC1(ADC1)), U_PAD_1.P$1
PAD_02: R_PAD_02.2, U_ATMEGA328.25 (PC2(ADC2)), U_PAD_2.P$1
PAD_03: R_PAD_03.2, U_ATMEGA328.26 (PC3(ADC3)), U_PAD_3.P$1
RST: D_RST.A, J_PROG.3, R_RST.2, U_ATMEGA328.29 (PC6(/RESET))
SCK: J_PROG.4, U_ATMEGA328.17 (PB5(SCK))
VIN: C_VR_0.1, J_CON_00.P2 (2), J_CON_02.P2 (2), U_VR_0.1 (VIN)

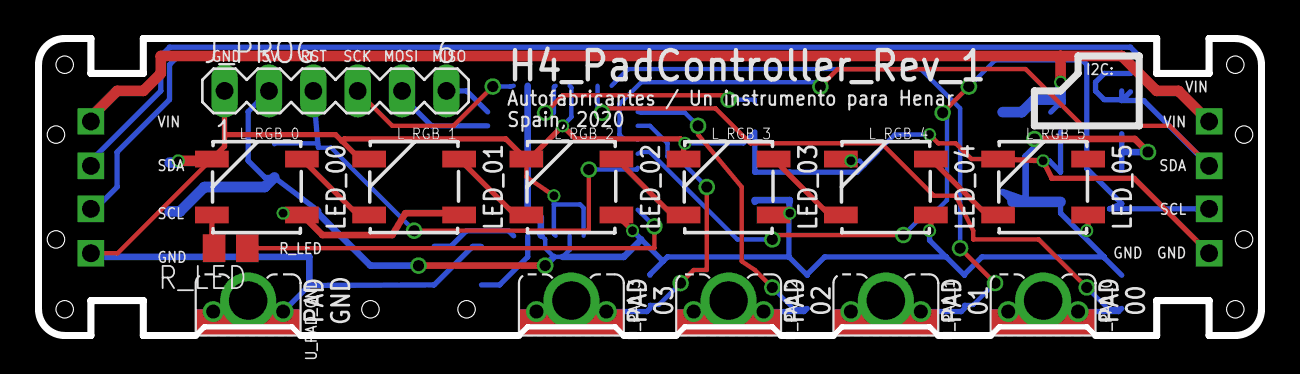
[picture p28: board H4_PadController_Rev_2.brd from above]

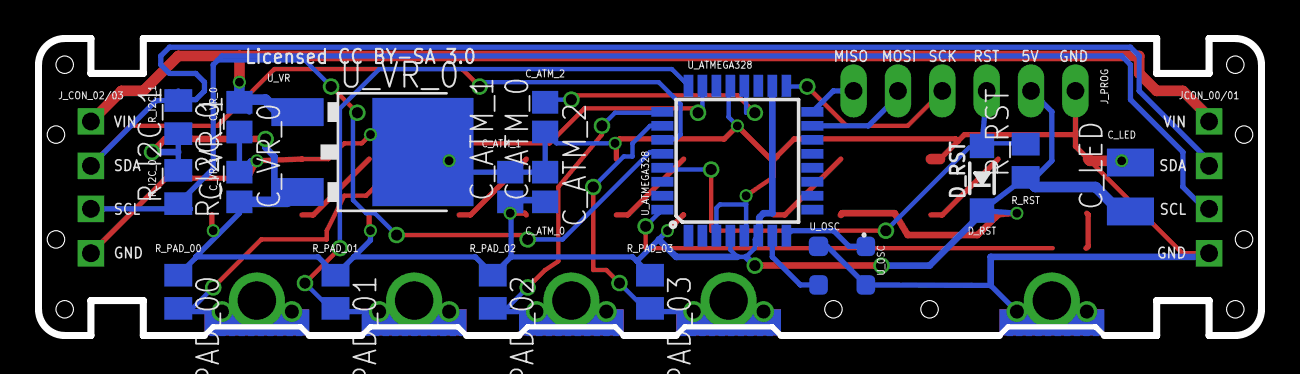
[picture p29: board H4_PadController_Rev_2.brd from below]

Board: 2 copper layers, 70.0 x 17.0 mm, 34 parts (17 on the bottom side), 23 nets.

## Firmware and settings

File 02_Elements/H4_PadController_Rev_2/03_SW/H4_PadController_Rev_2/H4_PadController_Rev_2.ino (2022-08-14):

/*
   @author Pablo dMM (Pablodmm.isp@gmail.com)
   @brief  Part of the Henar#4 Project. https://github.com/Autofabricantes/Henar-4 .This code controls 8 padNote, 1 padInstrument and 1 padOctave
   @date   2020_10_27
*/

// Library Import
#include <Wire.h>
#include "H4_LEDPad.h"
#include "H4_AnalogPad.h"
#include "H4_Configuration.h"
#include <EEPROM.h>
// Modes
#define PAD_TESTING
#define FIXED_I2C_DIR
// -----------------------------------------------------------------------------------------------------------------------------------------
// ---------------------------------------------------System Pin Definition-----------------------------------------------------------------
// -----------------------------------------------------------------------------------------------------------------------------------------
// Pin Definition Arduino Megsa
/*  const int I2C_SCL			      = 3;
  const int I2C_SCK			      = 3;
  const int pLED              = 2;
  const int pPAD_0            = A0;
  const int pPAD_1            = A0;
  const int pPAD_2            = A0;
  const int pPAD_3            = A0;*/

// Pin Definition Arduino ATMEGA328 (UNO)
const int I2C_SCL           = A4;
const int I2C_SCK           = A5;
const int pLED              = 2;
const int pPAD_0            = A0;
const int pPAD_1            = A1;
const int pPAD_2            = A2;
const int pPAD_3            = A3;

// -----------------------------------------------------------------------------------------------------------------------------------------
// ---------------------------------------------------Control and Configuration values Definition-------------------------------------------
// -----------------------------------------------------------------------------------------------------------------------------------------
// Constant Value Definition
const byte i2cDIR                = 8;

const byte FixedI2cDIR           = 17;

const bool OFF                  = 0;
const bool ON                   = 1;
const byte STABILIZATION_ITERATOR = 200;

// -----------------------------------------------------------------------------------------------------------------------------------------
// ---------------------------------------------------Custom Configuration Structs----------------------------------------------------------
// -----------------------------------------------------------------------------------------------------------------------------------------

// I2C Values
const byte SET_I2CDIR            = 1;
const byte SET_COLOR             = 2;
const byte GET_COLOR             = 3;
const byte SET_CH                = 4;
const byte GET_CH                = 5;
const byte GET_PAD               = 6;
const byte SET_DEFAULT           = 7;
const byte SET_DEFAULT_NOI2CDIR  = 8;
const byte SET_LEDACTIVITY       = 9;
const byte SET_RESET             = 10;

// LED Activity IDs
const byte LED_ID_ALLSTRIPE      = 0;
const byte LED_ID_SETOFF         = 1;
const byte LED_ID_BLINKCOLOR     = 2;
const byte LED_ID_FADEFROMNUCLEO = 3;
const byte LED_ID_FADEANDOFFCOLOR_FROMNUCLEO = 4;

// -----------------------------------------------------------------------------------------------------------------------------------------
// ---------------------------------------------------Global Variables----------------------------------------------------------------------
// -----------------------------------------------------------------------------------------------------------------------------------------

//------------------------------------------------------------------------------------------------------------------------------------------


H4_LEDPad LED(pLED);
H4_AnalogPad PAD_0(pPAD_0, false, 0);
H4_AnalogPad PAD_1(pPAD_1, false, 0);
H4_AnalogPad PAD_2(pPAD_2, false, 0);
H4_AnalogPad PAD_3(pPAD_3, false, 0);
H4_Configuration  CONFIGURATION;
char requestBuffer[10] = {0, 0, 0, 0, 0, 0, 0, 0, 0, 0};
byte requestBufferLength = 10;

// PAD Flags
char PAD_ACTIVE_0 = 0;
char PAD_ACTIVE_1 = 0;
char PAD_ACTIVE_2 = 0;
char PAD_ACTIVE_3 = 0;
//

int inMssg[10] = {0, 0, 0, 0, 0, 0, 0, 0, 0, 0};
boolean recievedWireCmd = false;
boolean i2cConnected = false;
// Led Activity Flags:
boolean performLedActivity    = false;
byte ledActivity_id            = 0;
byte ledActivity_primaryCode   = 0;
byte ledActivity_secondaryCode = 0;
byte ledActivity_duration      = 0;

void(* resetFunc) (void) = 0;

void setup() {
  Serial.begin(115200);
  CONFIGURATION.init();
  CONFIGURATION.loadConfiguration();

  PAD_0 = H4_AnalogPad(pPAD_0, CONFIGURATION.CONF.CH_On_0, CONFIGURATION.CONF.CH_Thr_0);
  PAD_1 = H4_AnalogPad(pPAD_1, CONFIGURATION.CONF.CH_On_1, CONFIGURATION.CONF.CH_Thr_1);
  PAD_2 = H4_AnalogPad(pPAD_2, CONFIGURATION.CONF.CH_On_2, CONFIGURATION.CONF.CH_Thr_2);
  PAD_3 = H4_AnalogPad(pPAD_3, CONFIGURATION.CONF.CH_On_3, CONFIGURATION.CONF.CH_Thr_3);

  LED.init();
  delay(1000);
  PAD_0.init();
  PAD_1.init();
  PAD_2.init();
  PAD_3.init();
  Serial.begin(115200);
  // i2C Initialization
  Serial.print("I2C DIR: ");
#ifdef FIXED_I2C_DIR  
  // With the Fixed I2C configuration, the device I2C is not retrieved through EEPROM but directly set through a CONST to avoid EEPROM corruption
  CONFIGURATION.CONF.i2cDIR_Stored = FixedI2cDIR;
  Wire.begin(FixedI2cDIR);
#else
  Wire.begin(CONFIGURATION.CONF.i2cDIR_Stored);
#endif
  Serial.println(CONFIGURATION.CONF.i2cDIR_Stored);
  //Wire.begin(8);
  Wire.onReceive(receiveEvent); // register event
  Wire.onRequest(requestEvent); // register event
  // Marks the start of operations
  //Pad Stabilization

  for (int i = 0; i > STABILIZATION_ITERATOR; i++) {
    PAD_0.readPad();
    PAD_1.readPad();
    PAD_2.readPad();
    PAD_3.readPad();
  }

  // When initialized, do not perform any activity until contacted through I2C. This is to detect errors
  while(!i2cConnected){
    ledActivity(LED_ID_FADEFROMNUCLEO, RED_LOW, BLACK_OFF, CONFIGURATION.CONF.fadeDuration);
  }
  LED.fadeColor_fromNucleo(CONFIGURATION.CONF.primaryColor, CONFIGURATION.CONF.secondaryColor, CONFIGURATION.CONF.fadeDuration);
}

/*
   LOOOOOOOOOOOOOOOOOOOOOOOOOOOOOOOOOOOOOOOOOOOOOOOOOOOOOOOOOOOOOOOOOOOOOOOOOOOOOOOOOOOOOP
*/
void loop() {
  if (performLedActivity) {
    ledActivity(ledActivity_id, ledActivity_primaryCode, ledActivity_secondaryCode, ledActivity_duration);
  }

  if (recievedWireCmd) {
    CONFIGURATION.saveConfiguration();
    recievedWireCmd = false;
  }
  // READ PAD 0
  //LED.fadeColor_fromNucleo(CONFIGURATION.CONF.secondaryColor, CONFIGURATION.CONF.primaryColor, CONFIGURATION.CONF.fadeDuration);
  if (CONFIGURATION.CONF.CH_On_0) {
    PAD_0.readPad();
    if ((!PAD_ACTIVE_0) && PAD_0.get_isPadActivated()) {
      Serial.println("0-> I GO UP!");
      PAD_ACTIVE_0 = 1;
      LED.fadeColor_fromNucleo(CONFIGURATION.CONF.secondaryColor, CONFIGURATION.CONF.primaryColor, CONFIGURATION.CONF.fadeDuration);

    }

    if ((PAD_ACTIVE_0) && !PAD_0.get_isPadActivated()) {
      Serial.println("0-> I GO DOWN!");
      PAD_ACTIVE_0 = 0;
      LED.fadeColor_fromNucleo(CONFIGURATION.CONF.primaryColor, CONFIGURATION.CONF.secondaryColor, CONFIGURATION.CONF.fadeDuration);

    }
  }
  // READ PAD 1
  if (CONFIGURATION.CONF.CH_On_1) {
    PAD_1.readPad();
    if ((!PAD_ACTIVE_1) && PAD_1.get_isPadActivated()) {
      Serial.println("1-> I GO UP!");
      PAD_ACTIVE_1 = 1;
      LED.fadeColor_fromNucleo(CONFIGURATION.CONF.secondaryColor, CONFIGURATION.CONF.primaryColor, CONFIGURATION.CONF.fadeDuration);

    }

    if ((PAD_ACTIVE_1) && !PAD_1.get_isPadActivated()) {
      Serial.println("1-> I GO DOWN!");
      PAD_ACTIVE_1 = 0;
      LED.fadeColor_fromNucleo(CONFIGURATION.CONF.primaryColor, CONFIGURATION.CONF.secondaryColor, CONFIGURATION.CONF.fadeDuration);

    }
  }
  // READ PAD 2
  if (CONFIGURATION.CONF.CH_On_2) {
    PAD_2.readPad();
    if ((!PAD_ACTIVE_2) && PAD_2.get_isPadActivated()) {
      Serial.println("2-> I GO UP!");
      PAD_ACTIVE_2 = 1;
      LED.fadeColor_fromNucleo(CONFIGURATION.CONF.secondaryColor, CONFIGURATION.CONF.primaryColor, CONFIGURATION.CONF.fadeDuration * 10);

    }

    if ((PAD_ACTIVE_2) && !PAD_2.get_isPadActivated()) {
      Serial.println("2-> I GO DOWN!");
      PAD_ACTIVE_2 = 0;
      LED.fadeColor_fromNucleo(CONFIGURATION.CONF.primaryColor, CONFIGURATION.CONF.secondaryColor, CONFIGURATION.CONF.fadeDuration * 10);
    }
  }
  // READ PAD 3
  if (CONFIGURATION.CONF.CH_On_3) {
    PAD_3.readPad();
    if ((!PAD_ACTIVE_3) && PAD_3.get_isPadActivated()) {
      Serial.println("3-> I GO UP!");
      PAD_ACTIVE_3 = 1;
      LED.fadeColor_fromNucleo(CONFIGURATION.CONF.secondaryColor, CONFIGURATION.CONF.primaryColor, CONFIGURATION.CONF.fadeDuration * 10);

    }

    if ((PAD_ACTIVE_3) && !PAD_3.get_isPadActivated()) {
      Serial.println("3-> I GO DOWN!");
      PAD_ACTIVE_3 = 0;
      LED.fadeColor_fromNucleo(CONFIGURATION.CONF.primaryColor, CONFIGURATION.CONF.secondaryColor, CONFIGURATION.CONF.fadeDuration * 10);
    }
  }
  delay(5);
}

void ledActivity(int id, int primaryCode, int secondaryCode, int duration) {
  performLedActivity = false; // Clear activation flag
  switch (id) {
    case LED_ID_ALLSTRIPE:
      LED.setAllStripe(primaryCode);
      break;
    case LED_ID_SETOFF:
      LED.setOff();
      break;
    case LED_ID_BLINKCOLOR:
      LED.blinkColor(primaryCode, duration);
      break;
    case LED_ID_FADEFROMNUCLEO:
      LED.fadeColor_fromNucleo(primaryCode, secondaryCode, duration);
      break;
    case LED_ID_FADEANDOFFCOLOR_FROMNUCLEO:
      LED.fadeandOffColor_fromNucleo(primaryCode, secondaryCode, duration);
      break;
    default:
      break;
  }
}

/*
   @function    void receiveEvent(int howMany)
   @description Processes the event of a Recieve I2C Message
   @param       int howMany    -> Not Sure what this is
   @return      none
*/
void receiveEvent(int howMany)
{
  i2cConnected = true;
  Serial.println("\nRecieve:");
  int i = 0;
  while (Wire.available()) { // loop through all but the last
    int in = Wire.read();    // receive byte as an integer
    inMssg[i] = in;
    Serial.print(inMssg[i]);
    Serial.print(" ");
    i++;
  }
  //recievedEvent = true;
  processMsg(inMssg);
  //Wire.write(requestBuffer, requestBufferLength);
}

/*
   @function    void requestEvent()
   @description Processes the event of a Reqeust I2C Message
   @param       none
   @return      none
*/
void requestEvent()
{
  i2cConnected = true;
  Serial.println("Request");
  Wire.write(requestBuffer, requestBufferLength);
}

/*
   @function    int processMsg(int inMssg[])
   @description Processes the incomming I2C Message and prepares the Buffer por a following i2C Request
   @param       int inMssg[]    -> Incomming message
   @return      none
*/
void processMsg(int inMssg[]) {
  recievedWireCmd = true;
  switch (inMssg[0]) {
    // Set the I2CDIR
    case SET_I2CDIR:
      Serial.println("\nSET_I2CDIR");
      //CONFIGURATION.set_defaultConfiguration();
      CONFIGURATION.CONF.i2cDIR_Stored = inMssg[1];
      //CONFIGURATION.saveConfiguration();
      requestBuffer[0] = SET_I2CDIR;
      requestBuffer[1] = CONFIGURATION.CONF.i2cDIR_Stored;
      requestBufferLength = 2;
      break;
    // Color LED Control
    case SET_COLOR:
      Serial.println("\nSET_COLOR");
      CONFIGURATION.CONF.primaryColor       = inMssg[1];
      CONFIGURATION.CONF.secondaryColor     = inMssg[2];
      CONFIGURATION.CONF.disconnectedColor  = inMssg[3];
      CONFIGURATION.CONF.connectedColor     = inMssg[4];
      CONFIGURATION.CONF.blinkDuration      = inMssg[5];
      CONFIGURATION.CONF.fadeDuration       = inMssg[6];
      //CONFIGURATION.saveConfiguration();
      // Prepare Request Buffer
      requestBuffer[0] = SET_COLOR;
      requestBuffer[1] = CONFIGURATION.CONF.primaryColor;
      requestBuffer[2] = CONFIGURATION.CONF.secondaryColor;
      requestBuffer[3] = CONFIGURATION.CONF.disconnectedColor;
      requestBuffer[4] = CONFIGURATION.CONF.connectedColor;
      requestBuffer[5] = CONFIGURATION.CONF.blinkDuration;
      requestBuffer[6] = CONFIGURATION.CONF.fadeDuration;
      requestBufferLength = 7;
      break;
    case GET_COLOR:
      Serial.println("\nGET_COLOR");
      requestBuffer[0] = GET_COLOR;
      requestBuffer[1] = CONFIGURATION.CONF.primaryColor;
      requestBuffer[2] = CONFIGURATION.CONF.secondaryColor;
      requestBuffer[3] = CONFIGURATION.CONF.disconnectedColor;
      requestBuffer[4] = CONFIGURATION.CONF.connectedColor;
      requestBuffer[5] = CONFIGURATION.CONF.blinkDuration;
      requestBuffer[6] = CONFIGURATION.CONF.fadeDuration;
      requestBufferLength = 7;
      break;
    // Channel ON/OFF Control
    case SET_CH:
      Serial.println("\nSET_CH");
      CONFIGURATION.CONF.CH_On_0 = inMssg[1];
      CONFIGURATION.CONF.CH_On_1 = inMssg[2];
      CONFIGURATION.CONF.CH_On_2 = inMssg[3];
      CONFIGURATION.CONF.CH_On_3 = inMssg[4];
      CONFIGURATION.CONF.CH_Thr_0 = inMssg[5];
      CONFIGURATION.CONF.CH_Thr_1 = inMssg[6];
      CONFIGURATION.CONF.CH_Thr_2 = inMssg[7];
      CONFIGURATION.CONF.CH_Thr_3 = inMssg[8];
      //CONFIGURATION.saveConfiguration();
      // Update Values
      PAD_0 = H4_AnalogPad(pPAD_0, CONFIGURATION.CONF.CH_On_0, CONFIGURATION.CONF.CH_Thr_0);
      PAD_1 = H4_AnalogPad(pPAD_1, CONFIGURATION.CONF.CH_On_1, CONFIGURATION.CONF.CH_Thr_1);
      PAD_2 = H4_AnalogPad(pPAD_2, CONFIGURATION.CONF.CH_On_2, CONFIGURATION.CONF.CH_Thr_2);
      PAD_3 = H4_AnalogPad(pPAD_3, CONFIGURATION.CONF.CH_On_3, CONFIGURATION.CONF.CH_Thr_3);
      // Prepare Responses
      requestBuffer[0] = SET_CH;
      requestBuffer[1] = CONFIGURATION.CONF.CH_On_0;
      requestBuffer[2] = CONFIGURATION.CONF.CH_On_1;
      requestBuffer[3] = CONFIGURATION.CONF.CH_On_2;
      requestBuffer[4] = CONFIGURATION.CONF.CH_On_3;
      requestBuffer[5] = CONFIGURATION.CONF.CH_Thr_0;
      requestBuffer[6] = CONFIGURATION.CONF.CH_Thr_1;
      requestBuffer[7] = CONFIGURATION.CONF.CH_Thr_2;
      requestBuffer[8] = CONFIGURATION.CONF.CH_Thr_3;
      requestBufferLength = 9;
      break;
    case GET_CH:
      Serial.println("\nGET_CH");
      requestBuffer[0] = GET_CH;
      requestBuffer[1] = CONFIGURATION.CONF.CH_On_0;
      requestBuffer[2] = CONFIGURATION.CONF.CH_On_1;
      requestBuffer[3] = CONFIGURATION.CONF.CH_On_2;
      requestBuffer[4] = CONFIGURATION.CONF.CH_On_3;
      requestBuffer[5] = CONFIGURATION.CONF.CH_Thr_0;
      requestBuffer[6] = CONFIGURATION.CONF.CH_Thr_1;
      requestBuffer[7] = CONFIGURATION.CONF.CH_Thr_2;
      requestBuffer[8] = CONFIGURATION.CONF.CH_Thr_3;
      requestBufferLength = 9;
      break;
    // Read Pad Result
    case GET_PAD:
      Serial.println("\nGET_PAD");
      requestBuffer[0] = GET_PAD;
      requestBuffer[1] = PAD_ACTIVE_0;
      requestBuffer[2] = PAD_ACTIVE_1;
      requestBuffer[3] = PAD_ACTIVE_2;
      requestBuffer[4] = PAD_ACTIVE_3;
      requestBuffer[5] = PAD_0.get_wasPadActivated();
      requestBuffer[6] = PAD_1.get_wasPadActivated();
      requestBuffer[7] = PAD_2.get_wasPadActivated();
      requestBuffer[8] = PAD_3.get_wasPadActivated();
      // Resets the values of the PAD_WAS_ACTIVE
      PAD_0.clear_wasPadActivated();
      PAD_1.clear_wasPadActivated();
      PAD_2.clear_wasPadActivated();
      PAD_3.clear_wasPadActivated();
      requestBufferLength = 9;
      break;
    case SET_DEFAULT:
      Serial.println("\nSET_DEFAULT");
      CONFIGURATION.set_defaultConfiguration();
      CONFIGURATION.set_defaultI2cDirConfiguration();
      PAD_0 = H4_AnalogPad(pPAD_0, CONFIGURATION.CONF.CH_On_0, CONFIGURATION.CONF.CH_Thr_0);
      PAD_1 = H4_AnalogPad(pPAD_1, CONFIGURATION.CONF.CH_On_1, CONFIGURATION.CONF.CH_Thr_1);
      PAD_2 = H4_AnalogPad(pPAD_2, CONFIGURATION.CONF.CH_On_2, CONFIGURATION.CONF.CH_Thr_2);
      PAD_3 = H4_AnalogPad(pPAD_3, CONFIGURATION.CONF.CH_On_3, CONFIGURATION.CONF.CH_Thr_3);
      //CONFIGURATION.saveConfiguration();
      break;
    case SET_DEFAULT_NOI2CDIR:
      Serial.println("\nSET_DEFAULT_NOI2CDIR");
      CONFIGURATION.set_defaultConfiguration();
      PAD_0 = H4_AnalogPad(pPAD_0, CONFIGURATION.CONF.CH_On_0, CONFIGURATION.CONF.CH_Thr_0);
      PAD_1 = H4_AnalogPad(pPAD_1, CONFIGURATION.CONF.CH_On_1, CONFIGURATION.CONF.CH_Thr_1);
      PAD_2 = H4_AnalogPad(pPAD_2, CONFIGURATION.CONF.CH_On_2, CONFIGURATION.CONF.CH_Thr_2);
      PAD_3 = H4_AnalogPad(pPAD_3, CONFIGURATION.CONF.CH_On_3, CONFIGURATION.CONF.CH_Thr_3);
      //CONFIGURATION.saveConfiguration();
      break;
    case SET_LEDACTIVITY:
      Serial.println("\nSET_LEDACTIVITY");
      performLedActivity = true;
      ledActivity_id = inMssg[1];
      ledActivity_primaryCode = inMssg[2];
      ledActivity_secondaryCode = inMssg[3];
      ledActivity_duration = inMssg[4];
      break;
    case SET_RESET                                                                                                                                                                                                          :
      Serial.println("\nSET_RESET");
      resetFunc(); //call reset
      break;
    default:
      break;
  }
}

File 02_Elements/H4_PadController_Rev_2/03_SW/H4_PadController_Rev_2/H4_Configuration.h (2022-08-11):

/*
 * @author Pablo dMM (Pablodmm.isp@gmail.com)
 * @brief  Part of the Henar#4 Project. https://github.com/Autofabricantes/Henar-4 .
 * @date   2021_10_31
 */
#ifndef H4_ConfIGURATION_H
#define H4_ConfIGURATION_H

#include "Arduino.h"
#include <EEPROM.h>

const int SIGNATURE_ADDR = 0;  // EEPROM Signature Address
// Signature Value
const int SIGNATURE = 90;      // Signature 0x5A 0x01011010 -> Very hard to be random


const int INIT_ADDR = 1;  // EEPROM Init Address
// Default values for all the configuration parameters
const int DEFAULT_i2cDIR_Stored = 8;  // DEFAULT
const int DEFAULT_primaryColor = 14;      // CYAN_HIGH
const int DEFAULT_secondaryColor = 2;     // WHITE_LOW
const int DEFAULT_disconnectedColor = 4;  // RED_BRIGHT
const int DEFAULT_connectedColor = 8;     // BLUE_HIGH
const int DEFAULT_blinkDuration = 30;     // MS
const int DEFAULT_fadeDuration = 30;      // MS
const bool DEFAULT_CH_On_0 = 1;           // ON
const bool DEFAULT_CH_On_1 = 0;           // OFF
const bool DEFAULT_CH_On_2 = 0;           // OFF
const bool DEFAULT_CH_On_3 = 0;           // OFF
const int DEFAULT_CH_Thr_0 = 100;          // AVERAGE
const int DEFAULT_CH_Thr_1 = 100;          // AVERAGE
const int DEFAULT_CH_Thr_2 = 100;          // AVERAGE
const int DEFAULT_CH_Thr_3 = 100;          // AVERAGE


class H4_Configuration
{
  public:
    H4_Configuration();
    void init();
    bool checkSignature();
    void loadConfiguration();
    void saveConfiguration();
    void set_defaultConfiguration();
    void set_defaultI2cDirConfiguration();
    // Structure to easily manage all the parameters
    struct storedConfiguration{
        byte i2cDIR_Stored;
        byte primaryColor;
        byte secondaryColor;
        byte disconnectedColor;
        byte connectedColor;
        byte blinkDuration;
        byte fadeDuration;
        bool CH_On_0;
        bool CH_On_1;
        bool CH_On_2;
        bool CH_On_3;
        byte CH_Thr_0;
        byte CH_Thr_1;
        byte CH_Thr_2;
        byte CH_Thr_3;
    };

    storedConfiguration CONF;

    /*uint8_t get_i2cDIR_Stored();
    int get_primaryColor();
    int get_secondaryColor();
    int get_disconnectedColor();
    int get_connectedColor();
    bool get_CH_On_0();
    bool get_CH_On_1();
    bool get_CH_On_2();
    bool get_CH_On_3();
    int get_CH_Thr_0();
    int get_CH_Thr_1();
    int get_CH_Thr_2();
    int get_CH_Thr_3();

    void set_i2cDIR_Stored(uint8_t i2cDIR_Stored);
    void set_primaryColor(int primaryColor);
    void set_secondaryColor(int secondaryColor);
    void set_disconnectedColor(int disconnectedColor);
    void set_connectedColor(int connectedColor);
    void set_CH_On_0(bool CH_On_0);
    void set_CH_On_1(bool CH_On_1);
    void set_CH_On_2(bool CH_On_2);
    void set_CH_On_3(bool CH_On_3);
    void set_CH_Thr_0(int CH_Thr_0);
    void set_CH_Thr_1(int CH_Thr_1);
    void set_CH_Thr_2(int CH_Thr_2);
    void set_CH_Thr_3(int CH_Thr_3);*/

   

    
  private:
    //storedConfiguration _localConfiguration
};

#endif

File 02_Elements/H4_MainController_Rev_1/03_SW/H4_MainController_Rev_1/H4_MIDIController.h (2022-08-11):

/*
 * @author Pablo dMM (Pablodmm.isp@gmail.com)
 * @brief  Part of the Henar#4 Project. https://github.com/Autofabricantes/Henar-4 .
 * @date   2021_10_31
 */
#ifndef H4_MIDICONTROLLER_H
#define H4_MIDICONTROLLER_H

#include "Arduino.h"
//#include "H4_WireController.h"

const int NOTEDURATION          = 200;
const int nPADNOTE              = 18;
const byte MIN_MIDIVELOCITY     = 60;
const byte MAX_MIDIVELOCITY     = 127;

// PAD TYPES
const byte PADTYPE_NOTE         = 0;
const byte PADTYPE_CHANNEL      = 1;
const byte PADTYPE_OCTAVE       = 2;

// FIRST BYTE GENERAL
const byte NOTE_ON              = 144;
const byte NOTE_OFF             = 128;
const byte CONTROL              = 176;      
const byte INSTRUMENT           = 192; 

// SECOND BYTE GENERAL 
const byte CTRL_VOL             =   7;
const byte CTRL_MOD             =   1;
const byte CTRL_EFCT1           =  12;
const byte CTRL_EFCT2           =  13;
const byte CTRL_NOTEOFF         = 123;

// SECOND BYTE NOTE VALUES ------------------------------------------------------------------------------------------------------------------------------------
// OCTAVE 00              || OCTAVE 01               || OCTAVE 02               || OCTAVE 03              || OCTAVE 04               || OCTAVE 05
//-------------------------------------------------------------------------------------------------------------------------------------------------------------
const byte NOTE_C0  =  0  ;const byte NOTE_C1  = 12  ;const byte NOTE_C2  = 24  ;const byte NOTE_C3  = 36  ;const byte NOTE_C4  = 48  ;const byte NOTE_C5  = 60;
const byte NOTE_C0s =  1  ;const byte NOTE_C1s = 13  ;const byte NOTE_C2s = 25  ;const byte NOTE_C3s = 37  ;const byte NOTE_C4s = 49  ;const byte NOTE_C5s = 61;
const byte NOTE_D0  =  2  ;const byte NOTE_D1  = 14  ;const byte NOTE_D2  = 26  ;const byte NOTE_D3  = 38  ;const byte NOTE_D4  = 50  ;const byte NOTE_D5  = 62;
const byte NOTE_D0s =  3  ;const byte NOTE_D1s = 15  ;const byte NOTE_D2s = 27  ;const byte NOTE_D3s = 39  ;const byte NOTE_D4s = 51  ;const byte NOTE_D5s = 63;
const byte NOTE_E0  =  4  ;const byte NOTE_E1  = 16  ;const byte NOTE_E2  = 28  ;const byte NOTE_E3  = 40  ;const byte NOTE_E4  = 52  ;const byte NOTE_E5  = 64;
const byte NOTE_F0  =  5  ;const byte NOTE_F1  = 17  ;const byte NOTE_F2  = 29  ;const byte NOTE_F3  = 41  ;const byte NOTE_F4  = 53  ;const byte NOTE_F5  = 65;
const byte NOTE_F0s =  6  ;const byte NOTE_F1s = 18  ;const byte NOTE_F2s = 30  ;const byte NOTE_F3s = 42  ;const byte NOTE_F4s = 54  ;const byte NOTE_F5s = 66;
const byte NOTE_G0  =  7  ;const byte NOTE_G1  = 19  ;const byte NOTE_G2  = 31  ;const byte NOTE_G3  = 43  ;const byte NOTE_G4  = 55  ;const byte NOTE_G5  = 67;
const byte NOTE_G0s =  8  ;const byte NOTE_G1s = 20  ;const byte NOTE_G2s = 32  ;const byte NOTE_G3s = 44  ;const byte NOTE_G4s = 56  ;const byte NOTE_G5s = 68;
const byte NOTE_A0  =  9  ;const byte NOTE_A1  = 21  ;const byte NOTE_A2  = 33  ;const byte NOTE_A3  = 45  ;const byte NOTE_A4  = 57  ;const byte NOTE_A5  = 69;
const byte NOTE_A0s = 10  ;const byte NOTE_A1s = 22  ;const byte NOTE_A2s = 34  ;const byte NOTE_A3s = 46  ;const byte NOTE_A4s = 58  ;const byte NOTE_A5s = 70;
const byte NOTE_B0  = 11  ;const byte NOTE_B1  = 23  ;const byte NOTE_B2  = 35  ;const byte NOTE_B3  = 47  ;const byte NOTE_B4  = 59  ;const byte NOTE_B5  = 71;

// SECOND BYTE NOTE VALUES -----------------------------------------------------------------------------------------------------------
// OCTAVE 06              || OCTAVE 07               || OCTAVE 08               || OCTAVE 09               || OCTAVE 10           
//------------------------------------------------------------------------------------------------------------------------------------
const byte NOTE_C6  = 72  ;const byte NOTE_C7  = 84  ;const byte NOTE_C8  = 96  ;const byte NOTE_C9  =108  ;const byte NOTE_C10  =120;
const byte NOTE_C6s = 73  ;const byte NOTE_C7s = 85  ;const byte NOTE_C8s = 97  ;const byte NOTE_C9s =109  ;const byte NOTE_C10s =121;
const byte NOTE_D6  = 74  ;const byte NOTE_D7  = 86  ;const byte NOTE_D8  = 98  ;const byte NOTE_D9  =110  ;const byte NOTE_D10  =122;
const byte NOTE_D6s = 75  ;const byte NOTE_D7s = 87  ;const byte NOTE_D8s = 99  ;const byte NOTE_D9s =111  ;const byte NOTE_D10s =123;
const byte NOTE_E6  = 76  ;const byte NOTE_E7  = 88  ;const byte NOTE_E8  =100  ;const byte NOTE_E9  =112  ;const byte NOTE_E10  =124;
const byte NOTE_F6  = 77  ;const byte NOTE_F7  = 89  ;const byte NOTE_F8  =101  ;const byte NOTE_F9  =113  ;const byte NOTE_F10  =125;
const byte NOTE_F6s = 78  ;const byte NOTE_F7s = 90  ;const byte NOTE_F8s =102  ;const byte NOTE_F9s =114  ;const byte NOTE_F10s =126;
const byte NOTE_G6  = 79  ;const byte NOTE_G7  = 91  ;const byte NOTE_G8  =103  ;const byte NOTE_G9  =115;
const byte NOTE_G6s = 80  ;const byte NOTE_G7s = 92  ;const byte NOTE_G8s =104  ;const byte NOTE_G9s =116;
const byte NOTE_A6  = 81  ;const byte NOTE_A7  = 93  ;const byte NOTE_A8  =105  ;const byte NOTE_A9  =117;
const byte NOTE_A6s = 82  ;const byte NOTE_A7s = 94  ;const byte NOTE_A8s =106  ;const byte NOTE_A9s =118;
const byte NOTE_B6  = 83  ;const byte NOTE_B7  = 95  ;const byte NOTE_B8  =107  ;const byte NOTE_B9  =119;
const byte NONOTE   =127;
// -----------------------------------------------------------------------------------------------------------------------------------------
// ---------------------------------------------------Musical Parameters--------------------------------------------------------------------
// -----------------------------------------------------------------------------------------------------------------------------------------  

const byte CH_CONTROL               = 7;
const byte OFFSET_INSTRUMENT        = NOTE_A1;
const byte OFFSET_SCALE             = NOTE_A0;
const byte OFFSET_OCTAVER           = NOTE_B1;
const byte OFFSET_PRONATURAL        = NOTE_E1;
const byte OFFSET_BLE               = NOTE_G1s;
const byte OFFSET_MODE              = NOTE_C2;

const byte NATURAALSCALE       = 0;
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

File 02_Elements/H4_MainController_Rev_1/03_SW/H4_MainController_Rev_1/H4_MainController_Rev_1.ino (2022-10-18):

/*
 * @author Pablo dMM (Pablodmm.isp@gmail.com)
 * @brief  Part of the Henar#4 Project. https://github.com/Autofabricantes/Henar-4 .This code controls a full system consisting of:
 *         18x PadNotes
 *         01x PadInstrument (Double Pad)
 *         01x PadScaler  (Double Pad)
 *         01x PadMode (Double Pad)
 *         01x PadOctave
 *         01x PadProNatural
 *         01x PadVoiceCommand
 *         
 *         Please I now it sounds confusing, probably you should check the documentation first.
 * @date   2022_09_29
 */

// Library Import
#include <Wire.h>
#include "H4_PadController.h"
#include "H4_MIDIController.h"
#include "H4_LEDSignal.h"
// Modes
#define PAD_TESTING
// LEDSIGNALLING controls the LED in the MAINBoard to blink everytime a MIDI Message is sent. It does not work very well yet...
//#define LEDSIGNALLING
// -----------------------------------------------------------------------------------------------------------------------------------------
// ---------------------------------------------------System Pin Definition-----------------------------------------------------------------
// -----------------------------------------------------------------------------------------------------------------------------------------
#define LEDSIGNAL     6
// -----------------------------------------------------------------------------------------------------------------------------------------
// ---------------------------------------------------Control and Configuration values Definition-------------------------------------------
// -----------------------------------------------------------------------------------------------------------------------------------------
// Constant Value Definition
const bool OFF                  = 0;
const bool ON                   = 1;
const byte qPadNotes             = 18;
const byte OCTAVE_MIN            = 4;
const byte OCTAVE_MAX            = 5;
const byte INSTRUMENT_MIN        = 0;
const byte INSTRUMENT_MAX        = 5;
const byte SCALE_MIN             = 0;
const byte SCALE_MAX             = 5;
const byte NATURAL              = 0;
const byte PRO                  = 1;
const byte MODE_MIN             = 0;
const byte MODE_MAX             = 11;

const byte PadInstrumentColor[6][2] = {{TURQOUISE_HIGH, WHITE_LOW},
                            {GREEN_HIGH, WHITE_LOW},
                            {BLUE_HIGH, WHITE_LOW},
                            {ORANGE_HIGH, WHITE_LOW},
                            {PURPLE_HIGH, WHITE_LOW},
                            {ZIEL_HIGH, WHITE_LOW}
};

const byte PadOctaverColor[2][2] = {{BLUE_LOW, WHITE_LOW},
                            {BLUE_HIGH, WHITE_LOW}};

const byte PadProNaturalColor[2][2] = {{GREEN_LOW, WHITE_LOW},
                                      {PURPLE_LOW, WHITE_LOW}
};

const byte PadScalerColor[2][2] = {{BLACK_OFF, BLACK_OFF},
                                  {YELLOW_LOW, WHITE_LOW}
};

const byte PadModeColor[2][2] = {{BLACK_OFF, BLACK_OFF},
                                   {RED_LOW, WHITE_LOW}
};

const byte PadVoiceDescriptionColor[2][2] = {{RED_LOW, WHITE_LOW},
                                   {ORANGE_LOW, WHITE_LOW}
};

byte controlMessageInstrument[INSTRUMENT_MAX + 1] = {NOTE_C2, NOTE_C2s, NOTE_D2, NOTE_D2s, NOTE_G1s, NOTE_A1};
byte controlMessageOctaver[OCTAVE_MAX - OCTAVE_MIN + 1] = {NOTE_B1,NOTE_A1s};
byte controlMessageScaler[SCALE_MAX + 1] = {NOTE_A2, NOTE_A2s, NOTE_B2, NOTE_E2, NOTE_F2, NOTE_F2s};
byte controlMessageMode[MODE_MAX + 1] = {NOTE_C0, NOTE_C0s, NOTE_D0, NOTE_D0s, NOTE_E0, NOTE_F0,NOTE_F0s, NOTE_G0, NOTE_G0s, NOTE_A0, NOTE_A0s, NOTE_B0};
byte controlMessageProNatural[PRO + 1] = {NOTE_E1, NOTE_F1};

// -----------------------------------------------------------------------------------------------------------------------------------------
// ---------------------------------------------------Custom Configuration Structs----------------------------------------------------------
// -----------------------------------------------------------------------------------------------------------------------------------------

// -----------------------------------------------------------------------------------------------------------------------------------------
// ---------------------------------------------------Global Variables----------------------------------------------------------------------
// -----------------------------------------------------------------------------------------------------------------------------------------
int inMssg[10] = {0,0,0,0,0,0,0,0,0,0};

int PadProActivation[2][18] = {{1,1,1,1,1,1,1,1,1,1,1,1,1,1,1,1,1,1},
                              {1,0,1,1,0,1,0,1,1,0,1,0,1,0,1,1,0,1}};
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

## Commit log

2019-12-12 Created HW Project for the H4_PadController_Rev_1
    Ceeated HW Project for H4_PadController_Rev_1
    Ongoing.
    [H4_PadController_Rev_1.brd, H4_PadController_Rev_1.sch]
2020-01-07 Implemented H4_PadController_Rev_1 Schematic
    Added Provisional Mechanic LaserCuts for PADs.
    Implemented all Schematic despite 8to1 4051 Multiplexer (tomorrow ^.^ )
    [H4_PaMechanics_Conductive_Rev_1.dxf, H4_PaMechanics_Foam_Rev_1.brd, H4_PaMechanics_Foam_Rev_1.dxf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]
2020-01-08 Finished H4_PadController_Rev_1 Schematic
    The Schematic has been finished! Yay!
    [H4_PadController_Rev_1.brd, H4_PadController_Rev_1.sch]
2020-02-06 Added H4_VelostatPadTest_Full
    Added a test based on the H3_MIISmallController_Rev_1 with HW variations in order to test 8 padNote, 1 padChannel and 1 padOctave.
    First Test with BELA have been proven succesfull.
    Issues to consider regarding the padObject pointers still to be solved.
    [H4_VelostatPadTest_Full.ino]
2020-04-08 Plantilla PAD conductora
    Plantilla de 6x6 de la tela conductora pra el PAD
    [H4_PaMechanics_Conductive_Rev_2.dxf]
2020-04-08 Plantilla Pad Foam
    Plantilla 8x8 goma eva para el PAD
    [H4_PaMechanics_Foam_Rev_2.dxf]
2020-04-08 Plantilla PAD velostat
    Plantilla 7x7 velostat para el PAD
    [H4_PaMechanics_Velostat_Rev_2.dxf]
2020-04-11 Finished Routing H4_PadController_Rev_1
    Finished the Routing of the full Element H4_PadController_Rev_4.
    Need to make Silk, 3D model, Gerber Files and BOM.
    [H4_PadController_Rev_1.brd, H4_PadController_Rev_1.sch]
2020-04-12 H4_PadController_Rev_1 Finished Layout, Gerber Files and 3D Model
    The PCB has been finished and the Layout, Gerber Files and 3D Model Finished.
    TODO:
    Make a better Schematic
    Make a good BOM
    [H4_PadController_Rev_1.brd, H4_PadController_Rev_1.sch]
2020-04-22 Corrected Gerber Files
    [H4_PadController_Rev_1.GBL, H4_PadController_Rev_1.GBO, H4_PadController_Rev_1.GBP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]
2020-10-28 Created H4_PadController_Rev_1.ino and H4_PadController_Rev_1_BOM.txt
    Added:
    H4_PadController_Rev_1.ino -> SW for Board (Just definitions)
    H4_PadController_Rev_1_BOM.txt -> Simple BOM for the Board obtained from RS AMIDATA.
2021-11-17 New Functional Software for H4_PadController_Rev_1
    New Software implementing:
    - Custom Class for built-in LED Stripe
    - Custom Class for up to 4 PAD readers
    - Custom Class for EEPROM Saving and Configuration
    These classes have been tested in Arduino MEGA 2560, with real Velostat Pads
    [H4_PaMechanics_Conductive_Rev_1.dxf, H4_PaMechanics_Conductive_Rev_2.dxf, H4_PaMechanics_Foam_Rev_1.brd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]
2022-01-19 Added I2C Wire Functionality
    The H4_PadController_Rev_1 has now a I2C SLAVE Functionality with the following commands:
    SET_I2CDIR
    SET_COLOR
    GET_COLOR
    SET_CH
    GET_CH
    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
2022-01-25 Added control for ATMEGA328 (H4Pad Real Board)
    Added Pinout and unit test for H4_PadController_Rev_1 with ATMEGA328
2022-05-02 Full Upload on various Items
    For mechanics:
    - Uploaded cover files for H4_PadController_Rev_1 and Rev_2
    For H4_PadController_Rev_1
    - Full SW
    For H4_PadController_Rev_2:
    - Changes just in the footprint and minor layout changes.
    - SW Remains the same
    - Generated Gerber Files (GR)
    For H4_MainController_Rev_1:
    - Full Schematics (pre corrections)
    - Updated SW
    Documentation:
    - Various Documentation regarding the Tests taking place
    [Cubreplaca_henar-autofabricantes_V1.step, Cubreplaca_henar-autofabricantes_V2.step, H4_MainController_Rev_1.brd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]
2022-05-10 Finished H4_MainController_Rev_1
    Finished design and Gerber Files of H4_MainController_Rev_1.
    I sometimes wonder if this will be ever read even by a machine.
    [H4_MainController_Rev_1.GBL, H4_MainController_Rev_1.GBO, H4_MainController_Rev_1.GBP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]
2022-07-16 Wow I havent sleept today I'm on autopilot
    [H4_MainController_Rev_1.GBL, H4_MainController_Rev_1.GBO, H4_MainController_Rev_1.GBP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]
2022-07-19 Updated with fixed bugs and POR / NATURAL mode
    Multiple but not optimized improvements
    [H4_MIDIController.h, H4_MainController_Rev_1.ino, H4_PadController.cpp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]
2022-08-08 Wild Refactoring
    It is all so clean and works so well...
    I'm really happy about this release ^^
    [Project8_1.cfg]
2022-08-11 Changes in H4_PadController_Rev_2 and H4_MainController_Rev_1
    In H4_PadController_Rev_2:
    - Created FIXED_I2C_DIR to stablish a fixed I2c direction during programming to avoid EEPROM corruption
    In H4_MainController_Rev_1:
    - Created voiceSituationReport();
    - Fixed i2c Directions
    - Fixed I2c Voice and LED Commands to happen first after push
    [H4_Configuration.h, H4_LEDSignal.h, H4_MIDIController.h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]
2022-08-31 Added Diagrams and 3D Model
    Added Diagram for Wiki documentation.
    Added 3D Model & Images for Mechanics
    [Pro+Micro.skp, esp32-hb.skp]
2022-09-28 Fix to problems regarding the non use of currentMode and MIDI.MIDIOFF_FIX
    Implemented a solution for the two bugs.
    [H4_MainController_Rev_1.ino]
2022-10-18 Fixed Problems created in the previos fixes
    Also tricked the copiler by defining the functiions before setup()
    [H4_MainController_Rev_1.ino, H4_PadController.cpp]
2022-10-29 Update readme woth the possible improvements
    # Improvements to be done:
    The improvements that a new developper could implement would be:
    - Use the ESP32 as an I2C Slave to create a BLE MIDI
    - Improve code to allow for the use of the RGB LEDs in the H4_MainBoard (Was not done because of memory limits in Arduino Leonardo)
    - Correct the EEPROM corruption in H4_PadController

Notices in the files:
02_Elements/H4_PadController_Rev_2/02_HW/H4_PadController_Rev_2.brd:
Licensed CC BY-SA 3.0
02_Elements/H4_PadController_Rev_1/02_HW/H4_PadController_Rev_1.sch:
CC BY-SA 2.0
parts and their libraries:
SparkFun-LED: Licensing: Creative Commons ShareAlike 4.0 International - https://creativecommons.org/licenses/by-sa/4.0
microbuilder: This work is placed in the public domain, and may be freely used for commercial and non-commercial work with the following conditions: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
